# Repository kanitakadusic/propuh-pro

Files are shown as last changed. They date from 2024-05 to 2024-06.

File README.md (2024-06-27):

## Propuh Pro - Sistem za ventilaciju

Projekt u sklopu kursa _Ugradbeni sistemi_ u 2023/24. studijskoj godini.

Cilj ovog projekta je napraviti funkcionalno smart home rješenje koje se sastoji od više distribuiranih komponenti koje međusobno komuniciraju kako bi se uspostavio sistem za ventilaciju.
Sistem se sastoji iz dva dijela - kontrolnog i terenskog podsistema. Terenski dio realizuje ventilaciju dok kontrolni sistem omogućava korisniku uvid u rad i upravljanje ventilacijom.

Sistem primjenu može naći kako u stambenim i ugostiteljskim objektima u vidu ventilacije prostora boravka, tako i u industrijskim okruženjima gdje je potrebno nadzirati temperaturu prostora ili uređaja koji nije neposredno dostupan.

Pored kontrolnog uređaja, sistemom je moguće upravljati i nadzirati ga i putem mobilne aplikacije.

Video prezentacija: https://www.youtube.com/watch?v=3Y28UMO7dcY&t=24s

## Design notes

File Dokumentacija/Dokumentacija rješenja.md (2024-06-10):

# Kontrolni uređaj

## main.py

Zadatak je napraviti koristični interfejs gdje je moguće postaviti željenu temperaturu i brzinu ventilatora za sistem ventilacije.
Izgled interfejsa prošao je više iteracija. Originalna zamisao je bila interakcija sa dva moda ekrana - operacioni i konfiguracijski mod. Međutim, pokazalo se da je bolje imati ekran za konfiguraciju svake od stavki.

Osnovne stavke koje korisnik konfiguriše su:
* *Željena temperatura*
* *Kritična temperatura*
* *Brzina ventilatora*

Pored pogleda na ove tri vrijednosti, postoji i pogled na *mjerenu temperaturu*.

### Display

Za display korišten je LCD sa 16 kolona i 2 reda sa I2C modulom za jednostavniju implementaciju uz pomoć biblioteke [RPI-PICO-I2C-LCD](https://github.com/T-622/RPI-PICO-I2C-LCD). Ova biblioteka dosta pojednostavi rad sa pomenutim LCD ekranom ali se pokazala kao nedovoljno responzivna za češće osvježavanje ekrana. Konfiguracija dimenzija i izlaznih pinova displeja je data ispod. 

```python
from lcd_api import LcdApi
from pico_i2c_lcd import I2cLcd

# Display konfiguracija
I2C_ADDR = 0x27
I2C_NUM_ROWS = 2
I2C_NUM_COLS = 16

I2C_BUS = I2C(1, sda=Pin(26), scl=Pin(27), freq=400000)
LCD_DISPLAY = I2cLcd(I2C_BUS, I2C_ADDR, I2C_NUM_ROWS, I2C_NUM_COLS)
```
Sve interakcije sa ekranom, kao što je postavljanje ili uklanjanje sadržaja izvode se metodama *LCD_DISPLAY* objekta.

### Pogledi

Za rad sa modovima ekrana, uvedena je klasa InterfaceMode koja definiše dozvoljene modove ili poglede na informacije.

Mogući modovi interfejsa su:
* Current temp - zadnja izmjerena temperatura
* Target temp - željena temperatura
* Critical temp - temperatura pri kojoj se pali alarm
* Fan mode - mod ventilatora

Svaki od navedenih modova ima prateći pogled. U prvom redu ekrana ispisan je naziv pogleda dok je u drugom redu ispisana vrijednost.

Za navigaciju između modova i izmjene vrijednosti, koriste se tasteri. Ispis obrađuje funkcija *print_configuration()* koja se poziva nakon svakog klika na taster.

### Tasteri

Tasteri dostupni korisniku su:
* NEXT_MODE_BUTTON - GPIO16
* PREVIOUS_MODE_BUTTON - GPIO19
* INCREASE_BUTTON - GPIO17
* DECREASE_BUTTON - GPIO18

Ovim tasterima korisnik može mijenjati između četri pogleda te povećati i smanjivati vrijednosti u koracima. Nad svakim od tastera definisan je prekid koji poziva funkciju koja obavlja zadatak tog tastera.

```python
# Postavljanje hardverskih prekida
NEXT_MODE_BUTTON.irq(handler=next_mode, trigger=Pin.IRQ_RISING)
INCREASE_BUTTON.irq(handler=increase_value, trigger=Pin.IRQ_RISING)
DECREASE_BUTTON.irq(handler=decrease_value, trigger=Pin.IRQ_RISING)
PREVIOUS_MODE_BUTTON.irq(handler=previous_mode, trigger=Pin.IRQ_RISING)
```

#### Debouncing
Kako se za konfiguraciju vrijednosti koriste fizički tasteri, pogodno je uvesti funkciju za *debouncing*.
```python
debounce = 0

def debouncing():
    global debounce
    if ticks_diff(ticks_ms(), debounce) < DEBOUNCE_TIME_MS:
        return False
    else:
        debounce = ticks_ms()
        return True
```

Konstanta *DEBOUNCE_TIME_MS* određuje period na koji se blokira ponovni unos sa tastera. Vrijednost od 300ms je odabrana nakon više pokušaja upotrebe i dovoljno je kratka da ne dozvoljava bouncing bez značajno utjecaja na korisničko iskustvo.

#### Korak izmjene
Korak izmjene temperature je 0.5°C. Ova vrijednost za korak je odabrana jer predstavlja dobar kompromis između tačnosti senzora temperature i mogućnosti odabranog ventilatora.

Obzirom da vrijednosti koje se dostave sa terenskog uređaja nisu nužno zaokružene na najbližu polovinu stepena, za to se ovdje koristi funkcija:
```python
def round_to_nearest_half(value) -> float:
    return round(value * 2) / 2
```

[LM35](https://www.ti.com/lit/ds/symlink/lm35.pdf) - korišteni senzor, ima grešku reda 0.5°C pri 25°C.

### MQTT Komunikacija

Komunikacija sa terenskim uređajem postiže se putem MQTT brokera. Ovo se pokazalo kao veoma jednostavan pristup rješavanju problema komunikacije više uređaja.

#### WiFi konektivnost

Kako je za MQTT potrebna internet konekcija, potrebno je vršiti spajanje na WiFi mrežu. WiFI SSID i lozinka se konfigurišu u kodu na sljedeći način:
```python
import network

# WiFi konfiguracija
WIFI_SSID = "naziv_mreze"
WIFI_PASSWORD = "password1234"

# Povezivanje na internet
print("Connecting to WiFi: ", WIFI_SSID)
WIFI = network.WLAN(network.STA_IF)
WIFI.active(True)
WIFI.config(pm=0xA11140)
WIFI.connect(WIFI_SSID, WIFI_PASSWORD)

LCD_DISPLAY.putstr("Connecting...")

while not WIFI.isconnected():
    pass

print("Connected to network!")
print("IP address:", WIFI.ifconfig()[0])
```

Obzirom da je sva ostala funkcionalnost uređaja ovisna o internet konekciji, ekran i sve ostale funkcionalnosti su blokirane dok se ne uspostavi WiFi konekcija sa datom mrežom. Na ekranu ostaje ispisan tekst "Connecting..." sve dok se konekcija uspostavlja. Nakon spajanja, u konzoli se ispisuje poruka o uspjehu i lokalna IP adresa.

#### MQTT Broker i teme

MQTT servis postavljen je kako slijedi:
```python
import simple
# MQTT konfiguracija
MQTT_SERVER = "broker.hivemq.com"
MQTT_CLIENT_NAME = "Propuh-Pro-Control"

MQTT_TOPIC_TARGET_TEMP = b"Propuh-Pro/target_temp"
MQTT_TOPIC_CRITICAL_TEMP = b"Propuh-Pro/critical_temp"
MQTT_TOPIC_FAN_MODE = b"Propuh-Pro/fan_mode"
MQTT_TOPIC_MEASURED_TEMP = b"Propuh-Pro/measured_temp"

# Povezivanje na MQTT broker
CLIENT = simple.MQTTClient(client_id=MQTT_CLIENT_NAME, server=MQTT_SERVER, port=1883)
CLIENT.connect()
```

Za svaku od četri stavke, postavljena je tema na MQTT brokeru *broker.himemq.com*.

*target_temp*, *critical_temp* i *measured_temp* predstavljeni su kao realni brojevi dok *fan_mode* uzima jednu od 5 dozvojenih vrijednosti definisanih u FanMode klasi.

Postavljen je klijent MQTT serivsa putem kojeg se šalju i dobavljaju vrijednosti za navedene teme.

#### Slanje podataka

Ovaj uređaj štalje vrijednosti željene i kritične temperature te mod ventilatora.

Nakon bilo koje promjene vrijednosti od strane korisnika, postavlja se timer na 3 sekunde. Nakon 3 sekunde, poziva se funkcija *send_data* koja na broker postavlja navedene vrijednosti.

Ova pauza od 3 sekunde pokazala se kao pogodan pristup za slanje podataka. Obzirom da se ove vrijednosti u praksi ne mijenjaju isuviše često, nije očigledna potreba za periodičnim slanjem.

```python
# Slanje podataka putem MQTT
def send_data(timer):
    publish = str(fan_mode.get_mode())
    CLIENT.publish(MQTT_TOPIC_FAN_MODE, publish)

    publish = str(target_temp)
    CLIENT.publish(MQTT_TOPIC_TARGET_TEMP, publish)

    publish = str(critical_temp)
    CLIENT.publish(MQTT_TOPIC_CRITICAL_TEMP, publish)

    print("Sent!")
```

#### Dobavljanje podataka

Podaci sa MQTT brokera se dobavljaju periodično. Funkcija *recieve_data* se poziva nakon svake sekunde i dobavlja vrijednost mjerene temperature i mod ventilatora koji je potencijalno postavljen na moblinom uređaju.

Kada se ustanovi da je postavljena nova vrijednost na brokeru *check_msg* metodom MQTT klijenta, poziva se *custom_dispatcher* koji tumači dostavljenu poruku na osnovu teme.

```python
# Filtriranje primljenih poruka
def custom_dispatcher(topic, msg):

    if topic == MQTT_TOPIC_MEASURED_TEMP:
        message_arrived_measured_temp(topic, msg)
    elif topic == MQTT_TOPIC_FAN_MODE:
        message_arrived_fan_mode(topic, msg)

CLIENT.set_callback(custom_dispatcher)

# Pretplata na teme
CLIENT.subscribe(MQTT_TOPIC_MEASURED_TEMP)
CLIENT.subscribe(MQTT_TOPIC_FAN_MODE)

# Provjera pristiglih podataka na MQTT
def recieve_data(timer):
    CLIENT.check_msg()
    CLIENT.check_msg()

recieve_DATA_TIMER = Timer(period=1000, mode=Timer.PERIODIC, callback=recieve_data)
```

### Rad sa temperaturama

Za svaku od tema uvedena je varijabla koja će čuvati odgovarajuću vrijednost na uređaju kako bi se njima manipulisalo u ostatku programa.

```python
interface_mode = InterfaceMode()
fan_mode = FanMode()
current_temp = 0.0
target_temp = 21.0
critical_temp = 35.0
```

Navedene početne vrijednosti za *target_temp* i *critical_temp* su odabrane iz razloga što predstavljaju uobičajen opseg temperatura za stambene prostore, mada nema razloga zašto ne mogu biti u bilo kojem drugom opsegu.

Uvedeno je ograničenje oko minimalne razlike kritične i željene temperature. Najmanja razlika je 5.0°C. Ovo je vrijednost za koju možemo pouzdano tvrditi da neće doći do alarma isključivo zbog greške u mjerenju obzirom da korišteni senzor ([LM35](https://www.ti.com/lit/ds/symlink/lm35.pdf)) ima grešku reda 0.5°C pri 25°C. Ova minimalna razlika se može posebno konfigurisati putem izdvojene konstante.

```python
# Dozvoljena razlika željene i kritične temperature
MINIMUM_TEMP_DIFFERENCE = 5.0
```

#### Alarm

Kada mjerena temperatura dosegne kritičnu temperaturu, dolazi do stanja alarma. Kontrolni uređaj na ekranu ispisuje posebnu treptajuću poruku s ciljem da privuće pažnju i upozori na situaciju. Za to vrijeme, neće se ispisivati standardni pogledi. Poruka o alarmu se može skloniti tasterima za promjenu pogleda.

Za potrebe implementacije alarm pogleda, koristi se varibajla *alarm_now*. Varijabla *alarm* služi kao *flag* da se dogodilo prekoračenje temperature što trenutno nema drugih koristi ali otvara mogućnost za neku vrstu dijagnostike u budućnosti.

```python
# Da li se u toku rada programa pojavio alarm
alarm = False
# Da li je trenutno aktivan alarm
alarm_now = False
```

# Terenski uređaj

## main.py

Zadatak je mjeriti i dostavljati temperaturu okruženja, upravljati brzinom ventilatora i signalizirati trenutno stanje. Konfiguracija ovog uređaja se dobavlja sa MQTT brokera.

### Mjerenje temperature

Temperatura se mjeri [LM35](https://www.ti.com/lit/ds/symlink/lm35.pdf) senzorom koji ima grešku reda 0.5°C pri 25°C. Ovaj senzor je odabran zbog jednostavnosti implementacije i korištenja. U opticaju je bio i [DHT11](https://www.mouser.com/datasheet/2/758/dht11-technical-data-sheet-translated-version-1143054.pdf) ali ne nudi dovoljnu preciznost i stabilnost u mjerenjima koja je potrebna za ovakav sistem.

Za konkretan LM35 potrebno je odrediti kalibracijsko offset kako bi mjerenje bilo reprezentativno.

Kako očekujemo da se temperatura prostora neće značajno mijenjati u kratkom periodu vremena, korišteno je periodično uzorkovanje od 10 uzoraka. Na osnovu prosječne vrijednosti uzoraka se određuje temperatura. Kalibracijski offset, broj uzoraka i ulazni pin sa A/D konverzijom se konfigurišu u kodu konstantama navedenim ispod

```python
# LM35 konfiguracija
LM35_CALIBRATION_OFFSET = -1200
LM35_NUMBER_OF_SAMPLES = 10
LM35_SENSOR_PIN = ADC(Pin(28))
```

### Upravljanje ventilatorom

Ventilator se upravlja PWM signalom sa frekvencijom 500Hz. Obzirom da vrijeme za koje se mijenja brzina ventilatora nije od krucijalnog značaja, frekvencija PWM signala ne mora biti izrazito velika.

```python
FAN_PWM = PWM(Pin(22))
FAN_PWM.freq(500)
```

Tačan proračun brzine rada ventilatora provodi objekt klase FanSpeedController koja sadrži svu potrebnu logiku proračuna.

```python
fan_controller = FanSpeedController(22, 30, 22)
```
Detaljnije informacije o klasi FanSpeedController ponuđene su u nastavku (Pomoćne klase / FanSpeedController).

Za početne vrijednosti pri instanciranju odabrane su temperature 22°C za željenu, 30°C za kritičnu i 22°C za trenutnu. Ove vrijedonsti se ponovo postavljaju prvim dobavljanjem podataka sa MQTT servisa.

#### VU Metar

Brzinu i mod ventilatora moguće je vizuleno utvrditi na osnovu šest LED-ova koji svijetle proporcionalno brzini ventilatora

```python
FAN_VU_METER_LEDS = BusOut([4, 5, 6, 7, 8, 9])

# 0 (OFF)       -> 0 upaljenih LED
# 1 (SLOW)      -> 2 upaljene LED
# 2 (NORMAL)    -> 4 upaljene LED
# 3 (FAST)      -> 6 upaljenih LED
```

### Alarm

U slučaju da FanSpeedControler odredi da je trenutna temperatura previsoka, diže se alarm. 
U slučaju alarma, treperi LED i pali se zujalica kako bi se vizuelno i zvukom privukla pažnja korisnika.

Zujanje alarma se može ugasiti tasterom na uređaju, što omogućuje neometano servisiranje koje je eventualno potrebno.

```python
OVERHEATING_LED = Pin(11, Pin.OUT)

ALARM_PWM = PWM(Pin(27))
ALARM_PWM.freq(1000)

ALARM_OFF_BUTTON = Pin(0, Pin.IN)

# Klikom na taster se gasi alarm
ALARM_OFF_BUTTON.irq(handler=turn_alarm_off, trigger=Pin.IRQ_RISING)
```

### MQTT Konektivnost

#### WiFi konektivnost

Identično kao i na kontrolnom uređaju, prvo se uspostavlja WiFi konekcija.

```python
# WiFi konfiguracija 
WIFI_SSID = "naziv_mreze"
WIFI_PASSWORD = "password1234"

# Povezivanje na internet
print("Connecting to WiFi: ", WIFI_SSID)
WIFI = network.WLAN(network.STA_IF)
WIFI.active(True)
WIFI.config(pm=0xA11140) 
WIFI.connect(WIFI_SSID, WIFI_PASSWORD)

while not WIFI.isconnected():
    pass

print("Connected to network!")
print("IP address:", WIFI.ifconfig()[0])
```

#### MQTT Broker i teme

Broker i teme koje se koriste za komunikaciju su identične kao i na kontrolnom uređaju. Jedina razlika je u nazivu klijenta

```python
# MQTT konfiguracija
MQTT_SERVER = "broker.hivemq.com"
MQTT_CLIENT_NAME = "Propuh-Pro-Teren"

MQTT_TOPIC_TARGET_TEMP = b"Propuh-Pro/target_temp"
MQTT_TOPIC_CRITICAL_TEMP = b"Propuh-Pro/critical_temp"
MQTT_TOPIC_FAN_MODE = b"Propuh-Pro/fan_mode"
MQTT_TOPIC_MEASURED_TEMP = b"Propuh-Pro/measured_temp"
```

#### Slanje podataka

Terenski uređaj periodično (svakih 0.5 sekundi) šalje isključivo izmjerenu temperaturu nakon svakog uzorkovanja.

```python
# Povezivanje na MQTT broker
CLIENT = simple.MQTTClient(client_id=MQTT_CLIENT_NAME, server=MQTT_SERVER, port=1883)
CLIENT.connect()

# Uzorkovanje i slanje izmjerene temperature
def check_temperature(t):
    ...
    # Uzorkovanje
    ...
    publish = str(measured_temp)
    CLIENT.publish(MQTT_TOPIC_MEASURED_TEMP, publish)

# Tajmer za očitavanje vrijednosti LM35
CHECK_TEMP_TIMER = Timer(period=500, mode=Timer.PERIODIC, callback=check_temperature)
```

#### Dohvaćanje podataka

Podaci sa MQTT brokera se dobavljaju periodično. Funkcija *recieve_data* se poziva nakon svake sekunde i dobavlja vrijednost željene i kritične temperature i mod ventilatora koji je potencijalno postavljen na moblinom uređaju.

Kada se ustanovi da je postavljena nova vrijednost na brokeru *check_msg* metodom MQTT klijenta, poziva se *custom_dispatcher* koji tumači dostavljenu poruku na osnovu teme.

```python
# Filtriranje primljenih poruka
def custom_dispatcher(topic, msg):
    
    if topic == MQTT_TOPIC_FAN_MODE:
        message_arrived_fan_mode(topic, msg)
    elif topic == MQTT_TOPIC_CRITICAL_TEMP:
        message_arrived_critical_temp(topic, msg)
    elif topic == MQTT_TOPIC_TARGET_TEMP:
        message_arrived_target_temp(topic, msg)

# Pretplata na teme
CLIENT.set_callback(custom_dispatcher)
CLIENT.subscribe(MQTT_TOPIC_FAN_MODE)
CLIENT.subscribe(MQTT_TOPIC_CRITICAL_TEMP)
CLIENT.subscribe(MQTT_TOPIC_TARGET_TEMP)

# Provjera pristiglih podataka na MQTT
def recieve_data(t):
    CLIENT.check_msg()
    CLIENT.check_msg()
    CLIENT.check_msg()

# Tajmer za primanje podataka
RECIEVE_DATA_TIMER = Timer(period=1000, mode=Timer.PERIODIC, callback=recieve_data)
```

# Pomoćne klase

## InterfaceMode

InterfaceMode je pomoćna klasa koja enkapsulira broj i naziv modova ili pogleda na ekran. Ova klasa prati *State pattern* i omogućava promjenu u naredno ili prethodno stanje. Validna stanja su predstavljena kao cijeli brojevi pa se mogu međusobno porediti. Potreba za ovom klasom nastala je jer MicroPython ne poznaje enum klase.

Konstruktor ove klase može da primi jedan parametar - početni pogled, ali je podrazumijevana vrijednost TARGET_TEMP_CONFIG. Primjer instanciranja objekta je dat ispod.

```python
interface_mode = InterfaceMode(InterfaceMode.FAN_CONFIG)
```

Stanja koja ova klasa poznaje su:
```python
VALID_MODES = {
    TARGET_TEMP_CONFIG,
    CRITICAL_TEMP_CONFIG,
    FAN_CONFIG,
    OPERATIONAL,
}
MODE_NAMES = {
    TARGET_TEMP_CONFIG: "TARGET_TEMP_CONFIG",
    CRITICAL_TEMP_CONFIG: "CRITICAL_TEMP_CONFIG",
    FAN_CONFIG: "FAN_CONFIG",
    OPERATIONAL: "OPERATION",
}    
```

Dostupne metode su:
```python
def next(self)          # Naredni mod, ciklično
def previous(self)      # Prethodni mod, ciklično
def get_mode(self)      # Dohvati trenutni mod
def get_mode_name(self) # Dohvati naziv trenutnog moda
```

## FanMode

FanMode je također *State pattern* klasa ali za definisanje modova ventilatora. Tačan intenzitet rada ventilatora nije cilj ove klase. Zapravo, cilj ove klase je da se jasno definišu mogući modovi ventilatora i omogući jasna komunikacija. Kao i za InterfaceMode, stanja se interno čuvaju kao cijeli brojevi.

Konstruktor ove klase može da primi jedan parametar - početni mod, ali je podrazumijevana vrijednost OFF. Primjer instanciranja objekta je dat ispod.

```python
fan_mode = FanMode(FanMode.AUTO)
```

Stanja koja ova klasa poznaje su:
```python
MODE_NAMES = {
    OFF: "OFF",
    SLOW: "SLOW",
    MEDIUM: "MEDIUM",
    FAST: "FAST",
    AUTO: "AUTO",
}

VALID_MODES = {
    OFF,
    SLOW,
    MEDIUM,
    FAST,
    AUTO,
}    
```

Dostupne metode su:
```python
def next(self)          # Naredni mod, ciklično
def previous(self)      # Prethodni mod, ciklično
def get_mode(self)      # Dohvati trenutni mod
def get_mode_name(self) # Dohvati naziv trenutnog moda
```

## FanSpeedController

Za enkapsulaciju logike potrebne za određivanje brzine ventilatora na osnovu relevantnih parametara, kreirana je klasa FanSpeedController.

Parametri potrebni za rad ove klase su:
* target_temp   - double
* critical_temp - double
* current_temp  - double
* fan_mode      - FanMode objekt

Ove vrijednosti se ujedno proslijeđuju konstruktoru u navedenom redoslijedu. Za fan_mode je podrazumijevana vrijednost FanMode(FanMode.OFF).

Dostupne metode su:
```python
def update_current_speed(self)                  
# Proračun brzine na osnovu parametara

def set_fan_mode(self, new_fan_mode)            
# Postavljanje jednog od modova za ventilator

def get_fan_mode(self)                          
# Dobavljanje trenutnog moda za ventilator

def set_current_temp(self, new_current_temp)    
# Postavljanje trenutne temperature

def set_target_temp(self, new_target_temp)      
# Postavljanje željene temperature

def set_critical_temp(self, new_critical_temp)  
# Postavljanje kritične temperature

def is_alarm(self)                              
# Provjeri je li alarmantna temperatura

def get_speed_percent(self)                     
# Dohvati brzinu u procentima

def get_speed_u16(self)                         
# Dohvati temperaturu u opsegu [0, 65535]

def get_led_binary(self)                        
# Dohvati stanje LED-ova

def turn_alarm_off(self)                        
# Ugasi alarm
```

Opsezi brzine su:
```python
# 0 (OFF)       -> 0%
# 1 (SLOW)      -> 50%
# 2 (NORMAL)    -> 75%
# 3 (FAST)      -> 100%
```

Za automatski mod, proračun se vrši po opsezima proračunatog procenta kao:

```python
# < -0.1        -> OFF
# [-0.1, 0.05)  -> OFF/SLOW
# [0.05, 0.2)   -> SLOW
# [0.2, 0.3)    -> SLOW/NORMAL
# [0.3, 0.5)    -> NORMAL
# [0.5, 0.6)    -> NORMAL/FAST
# >= 0.6        -> FAST
```

## BusOut

Za potrebe rada sa nizom LED-ova, uvedena je klasa BusOut.

BusOut omogućujue upravljanjem sa više digitalnih izlaza istovremeno tako što se proslijedi cijeli broj koji predstavlja željeno stanje izlaza.

Primjer instanciranja i postavljanja vrijednosti:
```python
bus_out = BusOut(Pin(16), Pin(17), Pin(18))

bus_out.setValue(0b101)
# Pin 16 i 18 su uključeni dok je Pin 17 isključen
```

Dostupne metode su:
```python
def set_value(self, val)
# Postavlja zadatu vrijednost val (integer ili binarni broj)

def size(self)
# Dohvaća broj pinova okjima se upravlja

def get_value(self)
# Dohvaća trenutno postavljenu vrijednost

def shift_right(self, shift_amount=1)
# Pomjera vrijednost izlaza udesno za dati broj bita

def shift_left(self, shift_amount=1)
# Pomjera vrijednost izlaza ulijevo za dati broj bita
```

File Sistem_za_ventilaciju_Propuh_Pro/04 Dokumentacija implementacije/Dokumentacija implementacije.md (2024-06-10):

<!-- TOC -->
# Propuh Pro - Tehnička dokumentacija
Za potrebe detaljnog tehničkog razumijevanja, ovdje su ponuđeni implementacijski detalji i motivacije za rješenja važnih problema u procesu razvoja ovog sistema.

U nastavku su ponuđeni detalji tehničkim licima potrebni za održavanje i nadogradnju postojećih mogućnosti sistema.

<!-- TOC start (generated with https://github.com/derlin/bitdowntoc) -->

- [Kontrolni uređaj](#kontrolni-ureaj)
   * [main.py](#mainpy)
      + [Display](#display)
      + [Pogledi](#pogledi)
      + [Tasteri](#tasteri)
         - [Debouncing](#debouncing)
         - [Korak izmjene](#korak-izmjene)
      + [MQTT Komunikacija](#mqtt-komunikacija)
         - [WiFi konektivnost](#wifi-konektivnost)
         - [MQTT Broker i teme](#mqtt-broker-i-teme)
         - [Slanje podataka](#slanje-podataka)
         - [Dobavljanje podataka](#dobavljanje-podataka)
      + [Rad sa temperaturama](#rad-sa-temperaturama)
         - [Alarm](#alarm)
- [Terenski uređaj](#terenski-ureaj)
   * [main.py](#mainpy-1)
      + [Mjerenje temperature](#mjerenje-temperature)
      + [Upravljanje ventilatorom](#upravljanje-ventilatorom)
         - [VU Metar](#vu-metar)
      + [Alarm](#alarm-1)
      + [MQTT Konektivnost](#mqtt-konektivnost)
         - [WiFi konektivnost](#wifi-konektivnost-1)
         - [MQTT Broker i teme](#mqtt-broker-i-teme-1)
         - [Slanje podataka](#slanje-podataka-1)
         - [Dohvaćanje podataka](#dohvaanje-podataka)
- [Pomoćne klase](#pomone-klase)
   * [InterfaceMode](#interfacemode)
   * [FanMode](#fanmode)
   * [FanSpeedController](#fanspeedcontroller)
   * [BusOut](#busout)

<!-- TOC end -->

<!-- TOC -->
# Kontrolni uređaj
<!-- TOC -->
## main.py
Zadatak je napraviti koristični interfejs gdje je moguće postaviti željenu temperaturu i brzinu ventilatora za sistem ventilacije.
Izgled interfejsa prošao je više iteracija. Originalna zamisao je bila interakcija sa dva moda ekrana - operacioni i konfiguracijski mod. Međutim, pokazalo se da je bolje imati ekran za konfiguraciju svake od stavki.
Osnovne stavke koje korisnik konfiguriše su:
* *Željena temperatura*
* *Kritična temperatura*
* *Brzina ventilatora*
Pored pogleda na ove tri vrijednosti, postoji i pogled na *mjerenu temperaturu*.

<!-- TOC -->
### Display
Za display korišten je LCD sa 16 kolona i 2 reda sa I2C modulom za jednostavniju implementaciju uz pomoć biblioteke [RPI-PICO-I2C-LCD](https://github.com/T-622/RPI-PICO-I2C-LCD). Ova biblioteka dosta pojednostavi rad sa pomenutim LCD ekranom ali se pokazala kao nedovoljno responzivna za češće osvježavanje ekrana. Konfiguracija dimenzija i izlaznih pinova displeja je data ispod. 
```python
from lcd_api import LcdApi
from pico_i2c_lcd import I2cLcd

# Display konfiguracija
I2C_ADDR = 0x27
I2C_NUM_ROWS = 2
I2C_NUM_COLS = 16

I2C_BUS = I2C(1, sda=Pin(26), scl=Pin(27), freq=400000)
LCD_DISPLAY = I2cLcd(I2C_BUS, I2C_ADDR, I2C_NUM_ROWS, I2C_NUM_COLS)
```
Sve interakcije sa ekranom, kao što je postavljanje ili uklanjanje sadržaja izvode se metodama *LCD_DISPLAY* objekta.

<!-- TOC -->
### Pogledi
Za rad sa modovima ekrana, uvedena je klasa InterfaceMode koja definiše dozvoljene modove ili poglede na informacije.
Mogući modovi interfejsa su:
* Current temp - zadnja izmjerena temperatura
* Target temp - željena temperatura
* Critical temp - temperatura pri kojoj se pali alarm
* Fan mode - mod ventilatora

Svaki od navedenih modova ima prateći pogled. U prvom redu ekrana ispisan je naziv pogleda dok je u drugom redu ispisana vrijednost.

Za navigaciju između modova i izmjene vrijednosti, koriste se tasteri. Ispis obrađuje funkcija *print_configuration()* koja se poziva nakon svakog klika na taster.

<!-- TOC -->
### Tasteri
Tasteri dostupni korisniku su:
* NEXT_MODE_BUTTON - GPIO16
* PREVIOUS_MODE_BUTTON - GPIO19
* INCREASE_BUTTON - GPIO17
* DECREASE_BUTTON - GPIO18

Ovim tasterima korisnik može mijenjati između četri pogleda te povećati i smanjivati vrijednosti u koracima. Nad svakim od tastera definisan je prekid koji poziva funkciju koja obavlja zadatak tog tastera.
```python
# Postavljanje hardverskih prekida
NEXT_MODE_BUTTON.irq(handler=next_mode, trigger=Pin.IRQ_RISING)
INCREASE_BUTTON.irq(handler=increase_value, trigger=Pin.IRQ_RISING)
DECREASE_BUTTON.irq(handler=decrease_value, trigger=Pin.IRQ_RISING)
PREVIOUS_MODE_BUTTON.irq(handler=previous_mode, trigger=Pin.IRQ_RISING)
```
<!-- TOC -->
#### Debouncing
Kako se za konfiguraciju vrijednosti koriste fizički tasteri, pogodno je uvesti funkciju za *debouncing*.
```python
debounce = 0
def debouncing():
    global debounce
    if ticks_diff(ticks_ms(), debounce) < DEBOUNCE_TIME_MS:
        return False
    else:
        debounce = ticks_ms()
        return True
```
Konstanta *DEBOUNCE_TIME_MS* određuje period na koji se blokira ponovni unos sa tastera. Vrijednost od 300ms je odabrana nakon više pokušaja upotrebe i dovoljno je kratka da ne dozvoljava bouncing bez značajno utjecaja na korisničko iskustvo.

<!-- TOC -->
#### Korak izmjene
Korak izmjene temperature je 0.5°C. Ova vrijednost za korak je odabrana jer predstavlja dobar kompromis između tačnosti senzora temperature i mogućnosti odabranog ventilatora.
Obzirom da vrijednosti koje se dostave sa terenskog uređaja nisu nužno zaokružene na najbližu polovinu stepena, za to se ovdje koristi funkcija:
```python
def round_to_nearest_half(value) -> float:
    return round(value * 2) / 2
```
[LM35](https://www.ti.com/lit/ds/symlink/lm35.pdf) - korišteni senzor, ima grešku reda 0.5°C pri 25°C.

<!-- TOC -->
### MQTT Komunikacija
Komunikacija sa terenskim uređajem postiže se putem MQTT brokera. Ovo se pokazalo kao veoma jednostavan pristup rješavanju problema komunikacije više uređaja.

<!-- TOC -->
#### WiFi konektivnost
Kako je za MQTT potrebna internet konekcija, potrebno je vršiti spajanje na WiFi mrežu. WiFI SSID i lozinka se konfigurišu u kodu na sljedeći način:
```python
import network

# WiFi konfiguracija
WIFI_SSID = "naziv_mreze"
WIFI_PASSWORD = "password1234"

# Povezivanje na internet
print("Connecting to WiFi: ", WIFI_SSID)
WIFI = network.WLAN(network.STA_IF)
WIFI.active(True)
WIFI.config(pm=0xA11140)
WIFI.connect(WIFI_SSID, WIFI_PASSWORD)

LCD_DISPLAY.putstr("Connecting...")

while not WIFI.isconnected():
    pass

print("Connected to network!")
print("IP address:", WIFI.ifconfig()[0])
```
Obzirom da je sva ostala funkcionalnost uređaja ovisna o internet konekciji, ekran i sve ostale funkcionalnosti su blokirane dok se ne uspostavi WiFi konekcija sa datom mrežom. Na ekranu ostaje ispisan tekst "Connecting..." sve dok se konekcija uspostavlja. Nakon spajanja, u konzoli se ispisuje poruka o uspjehu i lokalna IP adresa.

<!-- TOC -->
#### MQTT Broker i teme
MQTT servis postavljen je kako slijedi:
```python
import simple
# MQTT konfiguracija
MQTT_SERVER = "broker.hivemq.com"
MQTT_CLIENT_NAME = "Propuh-Pro-Control"

MQTT_TOPIC_TARGET_TEMP = b"Propuh-Pro/target_temp"
MQTT_TOPIC_CRITICAL_TEMP = b"Propuh-Pro/critical_temp"
MQTT_TOPIC_FAN_MODE = b"Propuh-Pro/fan_mode"
MQTT_TOPIC_MEASURED_TEMP = b"Propuh-Pro/measured_temp"

# Povezivanje na MQTT broker
CLIENT = simple.MQTTClient(client_id=MQTT_CLIENT_NAME, server=MQTT_SERVER, port=1883)
CLIENT.connect()
```
Za svaku od četri stavke, postavljena je tema na MQTT brokeru *broker.himemq.com*.

*target_temp*, *critical_temp* i *measured_temp* predstavljeni su kao realni brojevi dok *fan_mode* uzima jednu od 5 dozvojenih vrijednosti definisanih u FanMode klasi.

Postavljen je klijent MQTT serivsa putem kojeg se šalju i dobavljaju vrijednosti za navedene teme.

<!-- TOC -->
#### Slanje podataka
Ovaj uređaj štalje vrijednosti željene i kritične temperature te mod ventilatora.
Nakon bilo koje promjene vrijednosti od strane korisnika, postavlja se timer na 3 sekunde. Nakon 3 sekunde, poziva se funkcija *send_data* koja na broker postavlja navedene vrijednosti.

Ova pauza od 3 sekunde pokazala se kao pogodan pristup za slanje podataka. Obzirom da se ove vrijednosti u praksi ne mijenjaju isuviše često, nije očigledna potreba za periodičnim slanjem.

```python
# Slanje podataka putem MQTT
def send_data(timer):
    publish = str(fan_mode.get_mode())
    CLIENT.publish(MQTT_TOPIC_FAN_MODE, publish)

    publish = str(target_temp)
    CLIENT.publish(MQTT_TOPIC_TARGET_TEMP, publish)

    publish = str(critical_temp)
    CLIENT.publish(MQTT_TOPIC_CRITICAL_TEMP, publish)

    print("Sent!")
```

<!-- TOC -->
#### Dobavljanje podataka
Podaci sa MQTT brokera se dobavljaju periodično. Funkcija *recieve_data* se poziva nakon svake sekunde i dobavlja vrijednost mjerene temperature i mod ventilatora koji je potencijalno postavljen na moblinom uređaju.
Kada se ustanovi da je postavljena nova vrijednost na brokeru *check_msg* metodom MQTT klijenta, poziva se *custom_dispatcher* koji tumači dostavljenu poruku na osnovu teme.
```python
# Filtriranje primljenih poruka
def custom_dispatcher(topic, msg):

    if topic == MQTT_TOPIC_MEASURED_TEMP:
        message_arrived_measured_temp(topic, msg)
    elif topic == MQTT_TOPIC_FAN_MODE:
        message_arrived_fan_mode(topic, msg)

CLIENT.set_callback(custom_dispatcher)

# Pretplata na teme
CLIENT.subscribe(MQTT_TOPIC_MEASURED_TEMP)
CLIENT.subscribe(MQTT_TOPIC_FAN_MODE)

# Provjera pristiglih podataka na MQTT
def recieve_data(timer):
    CLIENT.check_msg()
    CLIENT.check_msg()

recieve_DATA_TIMER = Timer(period=1000, mode=Timer.PERIODIC, callback=recieve_data)
```

<!-- TOC -->
### Rad sa temperaturama
Za svaku od tema uvedena je varijabla koja će čuvati odgovarajuću vrijednost na uređaju kako bi se njima manipulisalo u ostatku programa.
```python
interface_mode = InterfaceMode()
fan_mode = FanMode()
current_temp = 0.0
target_temp = 21.0
critical_temp = 35.0
```
Navedene početne vrijednosti za *target_temp* i *critical_temp* su odabrane iz razloga što predstavljaju uobičajen opseg temperatura za stambene prostore, mada nema razloga zašto ne mogu biti u bilo kojem drugom opsegu.

Uvedeno je ograničenje oko minimalne razlike kritične i željene temperature. Najmanja razlika je 5.0°C. Ovo je vrijednost za koju možemo pouzdano tvrditi da neće doći do alarma isključivo zbog greške u mjerenju obzirom da korišteni senzor ([LM35](https://www.ti.com/lit/ds/symlink/lm35.pdf)) ima grešku reda 0.5°C pri 25°C. Ova minimalna razlika se može posebno konfigurisati putem izdvojene konstante.
```python
# Dozvoljena razlika željene i kritične temperature
MINIMUM_TEMP_DIFFERENCE = 5.0
```

<!-- TOC -->
#### Alarm
Kada mjerena temperatura dosegne kritičnu temperaturu, dolazi do stanja alarma. Kontrolni uređaj na ekranu ispisuje posebnu treptajuću poruku s ciljem da privuće pažnju i upozori na situaciju. Za to vrijeme, neće se ispisivati standardni pogledi. Poruka o alarmu se može skloniti tasterima za promjenu pogleda.
Za potrebe implementacije alarm pogleda, koristi se varibajla *alarm_now*. Varijabla *alarm* služi kao *flag* da se dogodilo prekoračenje temperature što trenutno nema drugih koristi ali otvara mogućnost za neku vrstu dijagnostike u budućnosti.
```python
# Da li se u toku rada programa pojavio alarm
alarm = False
# Da li je trenutno aktivan alarm
alarm_now = False
```

<!-- TOC -->
# Terenski uređaj
<!-- TOC -->
## main.py
Zadatak je mjeriti i dostavljati temperaturu okruženja, upravljati brzinom ventilatora i signalizirati trenutno stanje. Konfiguracija ovog uređaja se dobavlja sa MQTT brokera.

<!-- TOC -->
### Mjerenje temperature
Temperatura se mjeri [LM35](https://www.ti.com/lit/ds/symlink/lm35.pdf) senzorom koji ima grešku reda 0.5°C pri 25°C. Ovaj senzor je odabran zbog jednostavnosti implementacije i korištenja. U opticaju je bio i [DHT11](https://www.mouser.com/datasheet/2/758/dht11-technical-data-sheet-translated-version-1143054.pdf) ali ne nudi dovoljnu preciznost i stabilnost u mjerenjima koja je potrebna za ovakav sistem.

Za konkretan LM35 potrebno je odrediti kalibracijsko offset kako bi mjerenje bilo reprezentativno.

Kako očekujemo da se temperatura prostora neće značajno mijenjati u kratkom periodu vremena, korišteno je periodično uzorkovanje od 10 uzoraka. Na osnovu prosječne vrijednosti uzoraka se određuje temperatura. Kalibracijski offset, broj uzoraka i ulazni pin sa A/D konverzijom se konfigurišu u kodu konstantama navedenim ispod
```python
# LM35 konfiguracija
LM35_CALIBRATION_OFFSET = -1200
LM35_NUMBER_OF_SAMPLES = 10
LM35_SENSOR_PIN = ADC(Pin(28))
```

<!-- TOC -->
### Upravljanje ventilatorom
Ventilator se upravlja PWM signalom sa frekvencijom 500Hz. Obzirom da vrijeme za koje se mijenja brzina ventilatora nije od krucijalnog značaja, frekvencija PWM signala ne mora biti izrazito velika.
```python
FAN_PWM = PWM(Pin(22))
FAN_PWM.freq(500)
```

Tačan proračun brzine rada ventilatora provodi objekt klase FanSpeedController koja sadrži svu potrebnu logiku proračuna.
```python
fan_controller = FanSpeedController(22, 30, 22)
```
Detaljnije informacije o klasi FanSpeedController ponuđene su u nastavku (Pomoćne klase / FanSpeedController).

Za početne vrijednosti pri instanciranju odabrane su temperature 22°C za željenu, 30°C za kritičnu i 22°C za trenutnu. Ove vrijedonsti se ponovo postavljaju prvim dobavljanjem podataka sa MQTT servisa.

<!-- TOC -->
#### VU Metar
Brzinu i mod ventilatora moguće je vizuleno utvrditi na osnovu šest LED-ova koji svijetle proporcionalno brzini ventilatora
```python
FAN_VU_METER_LEDS = BusOut([4, 5, 6, 7, 8, 9])

# 0 (OFF)       -> 0 upaljenih LED
# 1 (SLOW)      -> 2 upaljene LED
# 2 (NORMAL)    -> 4 upaljene LED
# 3 (FAST)      -> 6 upaljenih LED
```

<!-- TOC -->
### Alarm
U slučaju da FanSpeedControler odredi da je trenutna temperatura previsoka, diže se alarm. 
U slučaju alarma, treperi LED i pali se zujalica kako bi se vizuelno i zvukom privukla pažnja korisnika.

Zujanje alarma se može ugasiti tasterom na uređaju, što omogućuje neometano servisiranje koje je eventualno potrebno.
```python
OVERHEATING_LED = Pin(11, Pin.OUT)

ALARM_PWM = PWM(Pin(27))
ALARM_PWM.freq(1000)

ALARM_OFF_BUTTON = Pin(0, Pin.IN)

# Klikom na taster se gasi alarm
ALARM_OFF_BUTTON.irq(handler=turn_alarm_off, trigger=Pin.IRQ_RISING)
```

<!-- TOC -->
### MQTT Konektivnost
<!-- TOC -->
#### WiFi konektivnost
Identično kao i na kontrolnom uređaju, prvo se uspostavlja WiFi konekcija.
```python
# WiFi konfiguracija 
WIFI_SSID = "naziv_mreze"
WIFI_PASSWORD = "password1234"

# Povezivanje na internet
print("Connecting to WiFi: ", WIFI_SSID)
WIFI = network.WLAN(network.STA_IF)
WIFI.active(True)
WIFI.config(pm=0xA11140) 
WIFI.connect(WIFI_SSID, WIFI_PASSWORD)

while not WIFI.isconnected():
    pass

print("Connected to network!")
print("IP address:", WIFI.ifconfig()[0])
```

<!-- TOC -->
#### MQTT Broker i teme
Broker i teme koje se koriste za komunikaciju su identične kao i na kontrolnom uređaju. Jedina razlika je u nazivu klijenta
```python
# MQTT konfiguracija
MQTT_SERVER = "broker.hivemq.com"
MQTT_CLIENT_NAME = "Propuh-Pro-Teren"

MQTT_TOPIC_TARGET_TEMP = b"Propuh-Pro/target_temp"
MQTT_TOPIC_CRITICAL_TEMP = b"Propuh-Pro/critical_temp"
MQTT_TOPIC_FAN_MODE = b"Propuh-Pro/fan_mode"
MQTT_TOPIC_MEASURED_TEMP = b"Propuh-Pro/measured_temp"
```

<!-- TOC -->
#### Slanje podataka
Terenski uređaj periodično (svakih 0.5 sekundi) šalje isključivo izmjerenu temperaturu nakon svakog uzorkovanja.

```python
# Povezivanje na MQTT broker
CLIENT = simple.MQTTClient(client_id=MQTT_CLIENT_NAME, server=MQTT_SERVER, port=1883)
CLIENT.connect()

# Uzorkovanje i slanje izmjerene temperature
def check_temperature(t):
    ...
    # Uzorkovanje
    ...
    publish = str(measured_temp)
    CLIENT.publish(MQTT_TOPIC_MEASURED_TEMP, publish)

# Tajmer za očitavanje vrijednosti LM35
CHECK_TEMP_TIMER = Timer(period=500, mode=Timer.PERIODIC, callback=check_temperature)
```

<!-- TOC -->
#### Dohvaćanje podataka
Podaci sa MQTT brokera se dobavljaju periodično. Funkcija *recieve_data* se poziva nakon svake sekunde i dobavlja vrijednost željene i kritične temperature i mod ventilatora koji je potencijalno postavljen na moblinom uređaju.

Kada se ustanovi da je postavljena nova vrijednost na brokeru *check_msg* metodom MQTT klijenta, poziva se *custom_dispatcher* koji tumači dostavljenu poruku na osnovu teme.
```python
# Filtriranje primljenih poruka
def custom_dispatcher(topic, msg):
    
    if topic == MQTT_TOPIC_FAN_MODE:
        message_arrived_fan_mode(topic, msg)
    elif topic == MQTT_TOPIC_CRITICAL_TEMP:
        message_arrived_critical_temp(topic, msg)
    elif topic == MQTT_TOPIC_TARGET_TEMP:
        message_arrived_target_temp(topic, msg)

# Pretplata na teme
CLIENT.set_callback(custom_dispatcher)
CLIENT.subscribe(MQTT_TOPIC_FAN_MODE)
CLIENT.subscribe(MQTT_TOPIC_CRITICAL_TEMP)
CLIENT.subscribe(MQTT_TOPIC_TARGET_TEMP)

# Provjera pristiglih podataka na MQTT
def recieve_data(t):
    CLIENT.check_msg()
    CLIENT.check_msg()
    CLIENT.check_msg()

# Tajmer za primanje podataka
RECIEVE_DATA_TIMER = Timer(period=1000, mode=Timer.PERIODIC, callback=recieve_data)
```

<!-- TOC -->
# Pomoćne klase
<!-- TOC -->
## InterfaceMode
InterfaceMode je pomoćna klasa koja enkapsulira broj i naziv modova ili pogleda na ekran. Ova klasa prati *State pattern* i omogućava promjenu u naredno ili prethodno stanje. Validna stanja su predstavljena kao cijeli brojevi pa se mogu međusobno porediti. Potreba za ovom klasom nastala je jer MicroPython ne poznaje enum klase.

Konstruktor ove klase može da primi jedan parametar - početni pogled, ali je podrazumijevana vrijednost TARGET_TEMP_CONFIG. Primjer instanciranja objekta je dat ispod.
```python
interface_mode = InterfaceMode(InterfaceMode.FAN_CONFIG)
```

Stanja koja ova klasa poznaje su:
```python
VALID_MODES = {
    TARGET_TEMP_CONFIG,
    CRITICAL_TEMP_CONFIG,
    FAN_CONFIG,
    OPERATIONAL,
}
MODE_NAMES = {
    TARGET_TEMP_CONFIG: "TARGET_TEMP_CONFIG",
    CRITICAL_TEMP_CONFIG: "CRITICAL_TEMP_CONFIG",
    FAN_CONFIG: "FAN_CONFIG",
    OPERATIONAL: "OPERATION",
}    
```
Dostupne metode su:
```python
def next(self)          # Naredni mod, ciklično
def previous(self)      # Prethodni mod, ciklično
def get_mode(self)      # Dohvati trenutni mod
def get_mode_name(self) # Dohvati naziv trenutnog moda
```

<!-- TOC -->
## FanMode
FanMode je također *State pattern* klasa ali za definisanje modova ventilatora. Tačan intenzitet rada ventilatora nije cilj ove klase. Zapravo, cilj ove klase je da se jasno definišu mogući modovi ventilatora i omogući jasna komunikacija. Kao i za InterfaceMode, stanja se interno čuvaju kao cijeli brojevi.

Konstruktor ove klase može da primi jedan parametar - početni mod, ali je podrazumijevana vrijednost OFF. Primjer instanciranja objekta je dat ispod.
```python
fan_mode = FanMode(FanMode.AUTO)
```

Stanja koja ova klasa poznaje su:
```python
MODE_NAMES = {
    OFF: "OFF",
    SLOW: "SLOW",
    MEDIUM: "MEDIUM",
    FAST: "FAST",
    AUTO: "AUTO",
}

VALID_MODES = {
    OFF,
    SLOW,
    MEDIUM,
    FAST,
    AUTO,
}    
```

Dostupne metode su:
```python
def next(self)          # Naredni mod, ciklično
def previous(self)      # Prethodni mod, ciklično
def get_mode(self)      # Dohvati trenutni mod
def get_mode_name(self) # Dohvati naziv trenutnog moda
```

<!-- TOC -->
## FanSpeedController
Za enkapsulaciju logike potrebne za određivanje brzine ventilatora na osnovu relevantnih parametara, kreirana je klasa FanSpeedController.

Parametri potrebni za rad ove klase su:
* target_temp   - double
* critical_temp - double
* current_temp  - double
* fan_mode      - FanMode objekt

Ove vrijednosti se ujedno proslijeđuju konstruktoru u navedenom redoslijedu. Za fan_mode je podrazumijevana vrijednost FanMode(FanMode.OFF).

Dostupne metode su:
```python
def update_current_speed(self)                  
# Proračun brzine na osnovu parametara

def set_fan_mode(self, new_fan_mode)            
# Postavljanje jednog od modova za ventilator

def get_fan_mode(self)                          
# Dobavljanje trenutnog moda za ventilator

def set_current_temp(self, new_current_temp)    
# Postavljanje trenutne temperature

def set_target_temp(self, new_target_temp)      
# Postavljanje željene temperature

def set_critical_temp(self, new_critical_temp)  
# Postavljanje kritične temperature

def is_alarm(self)                              
# Provjeri je li alarmantna temperatura

def get_speed_percent(self)                     
# Dohvati brzinu u procentima

def get_speed_u16(self)                         
# Dohvati temperaturu u opsegu [0, 65535]

def get_led_binary(self)                        
# Dohvati stanje LED-ova

def turn_alarm_off(self)                        
# Ugasi alarm
```

Opsezi brzine su:
```python
# 0 (OFF)       -> 0%
# 1 (SLOW)      -> 50%
# 2 (NORMAL)    -> 75%
# 3 (FAST)      -> 100%
```

Za automatski mod, proračun se vrši po opsezima proračunatog procenta kao:
```python
# < -0.1        -> OFF
# [-0.1, 0.05)  -> OFF/SLOW
# [0.05, 0.2)   -> SLOW
# [0.2, 0.3)    -> SLOW/NORMAL
# [0.3, 0.5)    -> NORMAL
# [0.5, 0.6)    -> NORMAL/FAST
# >= 0.6        -> FAST
```

<!-- TOC -->
## BusOut
Za potrebe rada sa nizom LED-ova, uvedena je klasa BusOut.
BusOut omogućujue upravljanjem sa više digitalnih izlaza istovremeno tako što se proslijedi cijeli broj koji predstavlja željeno stanje izlaza.
Primjer instanciranja i postavljanja vrijednosti:
```python
bus_out = BusOut(Pin(16), Pin(17), Pin(18))
bus_out.setValue(0b101)
# Pin 16 i 18 su uključeni dok je Pin 17 isključen
```

Dostupne metode su:
```python
def set_value(self, val)
# Postavlja zadatu vrijednost val (integer ili binarni broj)

def size(self)
# Dohvaća broj pinova okjima se upravlja

def get_value(self)
# Dohvaća trenutno postavljenu vrijednost

def shift_right(self, shift_amount=1)
# Pomjera vrijednost izlaza udesno za dati broj bita

def shift_left(self, shift_amount=1)
# Pomjera vrijednost izlaza ulijevo za dati broj bita
```

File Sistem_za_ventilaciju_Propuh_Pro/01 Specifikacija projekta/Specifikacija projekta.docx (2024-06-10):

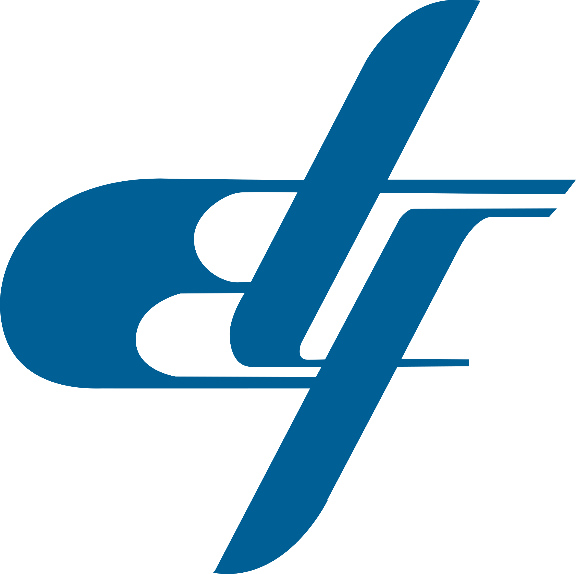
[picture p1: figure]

UNIVERZITET U SARAJEVU

ELEKTROTEHNIČKI FAKULTET

ODSJEK ZA RAČUNARSTVO I INFORMATIKU

UGRADBENI SISTEMI

Sistem za ventilaciju – Propuh Pro

PROJEKTNI ZADATAK

Studenti:

Merjem Gutošić

Kanita Kadušić

Mirza Mahmutović

Haris Mališević

Nastavni ansambl:

Red. prof. dr. Samim Konjicija, dipl. ing. el.

Selmir Gajip, mr. el. - dipl. ing. el.

Sarajevo, juni 2024.

# Sadržaj

# 1 Specifikacija projekta

Cilj ovog projekta je napraviti funkcionalno smart home rješenje, koje se sastoji od više distribuiranih komponenti koje međusobno komuniciraju. Imajući u vidu dostupne resurse i realnu primjenu u praksi, tema projekta je uspostavljanje sistema za ventilaciju.

Sistem se sastoji iz dva dijela – kontrolnog i terenskog podsistema. Terenski dio realizira ventilaciju dok kontrolni dio sistema omogućava korisniku uvid u rad terenskog podsistema i upravljanje njime.

Sistem primjenu može naći kako u stambenim i ugostiteljskim objektima u vidu ventilacije prostora boravka, tako i u industrijskim okruženjima gdje je potrebno nadzirati temperaturu prostora ili uređaja koji nije neposredno dostupan.

Pored kontrolnog uređaja, sistemom je moguće upravljati i nadzirati ga i putem mobilne aplikacije.

## 1.1 Funkcionalnosti sistema

### 1.1.1 Postavljanje željene i kritične temperature i režima rada ventilatora

U sklopu kontrolnog dijela sistema, korisnik ima mogućnost podešavanja željene i kritične temperature koristeći dva tastera (jedan za povećavanje, drugi za smanjivanje temperature). Također, korisnik može odabrati i željeni način rada ventilatora. O čemu se radi? Naime, ventilator ima četiri moguća režima:

- slabi – ventilator puše malom snagom
- srednji – ventilator puše srednjom snagom
- jaki – ventilator puše velikom snagom
- automatski – sistem, na osnovu odnosa trenutne, željene i kritične temperature, određuje optimalnu snagu ventilatora, u cilju postizanja željene temperature

Definisana željena temperatura figurira samo ukoliko se ventilator nalazi u automatskom režimu rada. Slabi, srednji i jaki režim rada podrazumijevaju da ventilator rashlađuje odgovarajućom snagom sve dok korisnik ne bude zahtijevao drugačije.

### 1.1.2 Praćenje visine temperature, režima i jačine puhanja ventilatora

Kontrolni podsistem daje uvid u kompletan rad sistema. Putem displeja se prikazuje trenutna temperatura, koja dolazi od strane terenskog podsistema, te režim rada ventilatora i jačina puhanja istog (displej, prikazom odgovarajućih znakova, realizira varijantu VU metra).

Jačina puhanja ventilatora u sklopu terenskog dijela sistema se prikazuje realizirajući VU metar uz pomoć LED dioda.

### 1.1.3 Mijenjanje prikaza displeja

Kontrolni podsistem daje mogućnost da se, pritiskom na odgovarajuće tastere, mijenja prikaz displeja. Dva prikaza podrazumijevaju podešavanje željene i kritične temperature (naravno, sistem vodi računa o validnosti unosa). Sljedeći prikaz omogućava kako podešavanje režima rada ventilatora, tako i praćenje njegove jačine puhanja (s obzirom da automatski režim sam pronalazi optimalanu jačinu puhanja). Četvrti, ujedno i posljednji prikaz, podrazumijeva ispis trenutne temperature koju dobija od strane terenskog podsistema.

### 1.1.4 Upozorenje pri dostizanju kritične temperature

Kako je već rečeno, korisnik definiše željenu i kritičnu temperaturu. Ukoliko terenski podsistem izmjeri temperaturu koja prelazi granicu definisanu kritičnom temperaturom, korisnik biva obaviješten slanjem upozorenja.

Upozorenje se realizira na dva načina. Prvi podrazumijeva prikaz upozorenja putem displeja u sklopu kontrolog podsistema, dok drugi podrazumijeva zvučno oglašavanje u sklopu terenskog podsistema. Osim alarma, koji se može ugasiti pritiskom na taster, odgovarajuća LED dioda blinka dok se situacija ne normalizuje i sistem ne resetuje.

### 1.1.5 Mijenjanje režima rada ventilatora putem mobilnog uređaja

Koristeći IoT MQTT Panel aplikaciju, korisnik ima mogućnost mijenjati režim rada ventilatora, neovisno od lokacije na kojoj se nalazi.

## 1.2 Hardverski resursi

### 1.2.1 PicoETF – kontrolni podsistem

| Komponenta | Opis | Količina
1 | taster | digitalni ulaz | 4
2 | LCD displej | izlazna komponenta | 1

### 1.2.2 Pico – terenski podsistem

| Komponenta | Opis | Količina
1 | LM35 temperaturni senzor | analogni ulaz | 1
2 | DC motor | PWM izlaz | 1
3 | LED dioda | digitalni izlaz | 7
4 | piezo (zvučnik/buzzer) | PWM izlaz | 1

### 1.2.3 Dodatna oprema

Od dodatne opreme, koristit će se i ventilator, mobilni uređaj, baterija 9V , otpornici, konektori, tranzistor, sigurnosna dioda i breadboard-i.

# 2 Zaključak

Što se tiče mogućih proširenja projekta, njih je moguće razmatrati u dva smjera. Sistem za ventilaciju je moguće nadograditi dodavanjem pomoćnih ventilatora. Na primjer, u automatskom režimu rada, pomoćni ventilator bi se uključivao kada sistem procijeni da nije u mogućnosti postići željenu temperaturu s jednim ventilatorom ili ukoliko sistem zaključi da bi rashlađivanje pomoću jednog ventilatora bilo isuviše sporo. S druge strane, u sistem bi se mogli dodati novi senzori, kao što su senzor dima i vlažnosti, čime bi se uvele nove funkcionalnosti kojima korisnik raspolaže.

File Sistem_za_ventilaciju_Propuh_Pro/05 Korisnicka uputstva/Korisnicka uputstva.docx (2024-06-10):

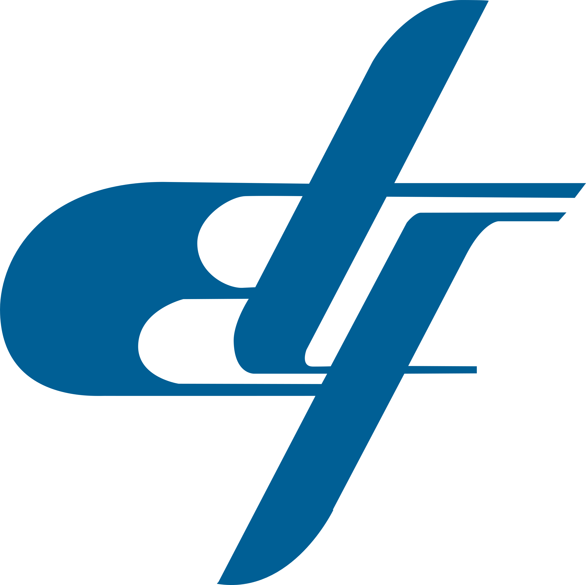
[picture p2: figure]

UNIVERZITET U SARAJEVU

ELEKTROTEHNIČKI FAKULTET

ODSJEK ZA RAČUNARSTVO I INFORMATIKU

UGRADBENI SISTEMI

Sistem za ventilaciju – Propuh Pro

Korisnička uputstva

Sarajevo, juni 2024.

# Poštovani korisnici

Ispred vas se nalazi uputstvo za upotrebu Propuh-Pro sistema za ventilaciju. Propuh-Pro predstavlja jednostavan smart home sistem čiji je glavni cilj regulisanje temperature prema željama korisnika korištenjem ventilatora. Nudi mogućnost podešavanja željene temperature i jačinu rada ventilatora od strane korisnika, podešavanje kritične temperature kao indikatora o performansama sistema, uvid u trenutnu temperaturu i podatke koji su uneseni, te vizuelnu i audio signalizaciju vezanu za rad sistema.

Sistem je jednostavan za korištenje i u potpunosti prilagođen korisniku. Sastoji se od kontrolnog i terenskog uređaja koji su međusobno povezani na programskom nivou. Dijelovi nisu povezani fizički pa sistem radi bez obzira na njihovu međusobnu udaljenost. Po želji, sistem je moguće nadzirati i podešavati i putem mobilne aplikacije, čime on postaje univerzalniji.

Propuh-Pro sistem za ventilaciju može se koristiti u bilo kojem prostoru i kontekstu vezanom za ventilaciju i regulaciju temperature, te njegov puni potencijal zavisi samo od mašte korisnika.

Molimo Vas da pročitate uputstva do kraja kako biste izbjegli bilo kakve nejasnoće.

# Sadržaj

# 1 Karakteristike

- Rashlađivanje

Osnovna svrha i mogućnost sistema je raslađivanje prostora na željenu temperaturu. Prostor i kontekst u kojem će se koristiti korisnik može prilagođavati po želji i u skladu sa veličinom ventilatora.

- Mjerenje trenutne temperature

Sistem ima ugrađen temperaturni senzor pomoću kojeg u toku rada mjeri trenutnu temperaturu u prostoru. Izmjerenu temperaturu je moguće vidjeti na ekranu kontrolnog sistema.

- Podešavanje temperature

Iako sistem sadrži unaprijed definisanu vrijednost željene temperature, poželjno je da se ista podesi u skladu sa namjenom sistema. Sistem će nastojati, prema konfiguracijama korisnika, da održi odabranu temperaturu.

- Podešavanje kritične temperature

Kritična temperatura je jedan od parametara sistema koji određuje njegovu funkcionalnost. Razlika između kritične i željene temperature ne smije biti manja od 5°C, u suprotnom sistem ne dopušta dalje smanjivanje kritične, odnosno povećavanje željene temperature

- Podešavanje jačine ventilatora

Pored temperature, potrebno je podesiti i jačinu rada ventilatora. Moguće je birati jedan od 4 moda:

1. OFF – sistem ne radi
2. SLOW – slabi intenzitet
3. MEDIUM – srednje jaki intenzitet
4. FAST – jaki intenzitet
5. AUTO – automatski režim rada (detaljnije objašnjen u nastavku)

Nakon podešavanja jačine rada ventilatora, ventilator započinje rad s jačinom u skladu s odabranom opcijom.

- Uvid u podatke

Na kontrolnom uređaju sistem pruža mogućnost pregleda unesenih parametara (jačine rada, željene i kritične temperature), kao i prikaz trenutne temperature u prostoru putem poruke na display-u.

Na terenskom uređaju jačina rada ventilatora vizuelno je prikazana u vidu VU metra putem LED dioda.

- AUTO mod rada ventilatora

Sistem ima mogućnost korištenja AUTO moda. U ovom modu, sistem samostalno podešava jačinu rada ventilatora, u zavisnosti od vrijednosti trenutne temperature.

- Kontrola sistema pomoću mobilne aplikacije

Po želji, jačina rada ventilatora može se kontrolisati i putem mobilne aplikacije. Željenu i kritičnu temperaturu, potrebno je regulisati putem kontrolnog uređaja.

- Fizička nezavisnost uređaja

Kontrolni i terenski uređaj nisu fizički spojeni i ne ovise od međusobne udaljenosti, pa sistem može da radi i kada se uređaji nalaze u različitim prostorijama.

- Signalizacija u slučaju dostizanja kritične temperature u prostoru

Ukoliko trenutna temperature dostigne vrijednost jednaku ili veću od kritične temperature, na terenskom uređaju pali se zvučni alarm i svjetlosna signalizacija putem posljednje LED diode na sistemu. Na kontrolnom uređaju prikazuje se odgovarajuća poruka.

Svrha signalizacija u ovom slučaju je ukazivanje korisniku od strane sistema da trenutni rad sistema nije u potpunosti prilagođen smanjivanju trenutne temperature.

# 2 Komponente

## 2.1 Kontrolni uređaj

Kontrolni uređaj služi za podešavanje parametara na osnovu kojih radi ventilator. Parametri koji se podešavaju su:

- željena temperatura
- jačina rada ventilatora
- kritična temperature

Na kontrolnom uređaju nalazi se display koji prikazuje unesene podatke i parametre sistema, te 4 dugmeta pomoću kojih se parametri unose i mijenja trenutni prikaz:

- prethodni korisnički mod
- smanji (temperaturu) / prethodni mod ventilatora
- povećaj (temperaturu) / sljedeći mod ventilatora
- sljedeći korisnički mod

## 2.2 Terenski uređaj

Terenski uređaj je uređaj koji realizuje samu ventilaciju te se u skladu s tim na njemu nalazi više komponenti:

- ventilator koji se pokreće i radi na osnovu podataka unesenih putem kontrolnog uređaja
- alarm koji je zadužen za zvučnu signalizaciju u slučaju da trenutna temperatura dostigne kritičnu temperaturu
- svjetlosne diode koje pružaju vizuelni prikaz trenutnog rada, tj. jačine rada ventilatora u vidu VU metra
- dugme za gašenje alarma
- temperaturni senzor

# 3 Upute za korištenje

## 3.1 Pokretanje sistema

Sistem neće raditi ukoliko neki od uređaja nije povezan na određenu WiFi mrežu, pa je prije samog korištenja i paljenja sistema neophodno obezbijediti stabilnu WiFi konekciju.

Oba uređaja sistema je potrebno povezati sa dotokom struje (kabl spojiti u utičnicu) što će pokrenuti paljenje sistema. Nakon paljenja, sistem će pristupiti procesu povezivanja sa WiFi mrežom, te će se na ekranu na kontrolnom uređaju prikazati poruka: "Connecting..."

Nakon povezivanja na ekranu će se prikazati podaci o željenoj temperaturi, što znači da je sistem povezan i spreman za rad.

## 3.2 Korisnički modovi

Parametri koji se unose, kao i informacije koje se prikazuju na ekranu ne prikazuju se i ne biraju se odjednom, nego u zavisnosti od odabranog korisničkog moda. Moguće je odabrati jedan od 4 moda:

- Željena temperatura – podešava se i prikazuje željena temperature u vidu poruke:

"Target temp: " + unesena temperatura

- Kritična temperatura – podešava se i prikazuje kritična temperature u vidu poruke:

"Critical temp: " + unesena temperatura

- Konfiguracija ventilatora – podešava se i prikazuje jačina rada ventilatora u vidu poruke:

"Fan speed: " + prikaz putem simbola + unesena jačina

- Trenutna temperatura – prikazuje se trenutna temperatura u prostoru u vidu poruke:

"Current temp: " + izmjerena temperatura

BITNO: Odgovarajući podaci se mogu podesiti i vidjeti samo ukoliko se sistem nalazi u odgovarajućem modu.

## 3.3 Prolazak kroz modove

Promjena modova realizuje se klikom na jedno od dva krajnja dugmeta:

  - krajnje lijevo dugme – jedan mod unazad
  - krajnje desno dugme – jedan mod naprijed

Prilikom klika na dugme prikaz na ekranu će se promijeniti i prikazati odgovarajuću poruku. Modovi se mijenjaju i ciklično tako da se kontinuiranim klikanjem na krajnje lijevo, odnosno krajnje desno dugme, sistem može vratiti u isti mod.

## 3.4 Podešavanje temperature

I željena i kritična temperatura se podešavaju na isti način na kontrolnom uređaju.

Prije podešavanja željene i kritične temperature bit će ponuđene početne vrijednosti:

- željena temperature: 21°C
- kritična temperature: 35°C

Da bi ventilator radio, nije neophodno mijenjati početne vrijednosti navedenih temperature. Međutim, preporučuje se prilagođavanje ovih temperatura samoj namjeni sistema.

Podešavanje temperature se vrši klikom na neko od dva dugmeta u sredini na kontrolnom uređaju na sljedeći način:

- smanjivanje temperature – drugo dugme po redu s lijeva za svaki klik željenu/kritičnu temperaturu smanjuje za 0.5°C
- povećavanje temperature – treće dugme po redu s lijeva za svaki klik željenu/kritičnu temperaturu povećava za 0.5°C

## 3.5 Podešavanje jačine rada ventilatora

Jačina ventilatora se slično kao i korisnički modovi može podesiti klikom na neko od dva dugmeta u sredini na kontrolnom uređaju na sljedeći način:

- jedan mod nazad – drugo dugme po redu s lijeva za svaki klik vraća mod ventilatora za jedan niže, tj. za svaki klik ventilator će puhati manjom jačinom
- jedan mod naprijed – treće dugme po redu s lijeva za svaki klik postavlja mod ventilatora za jedan više, tj. za svaki klik ventilator će puhati većom jačinom
- ukoliko se ventilator nalazi u FAST modu klikom za prelaz u sljedeći mod će se preći u AUTO mod
- kroz modove se kreće cirkularno prema prethodno navedenom rasporedu (nakon AUTO moda prelazi se u OFF ukoliko se prelazi naprijed i iz OFF moda se prelazi u AUTO mod ukoliko se prelazi naprijed)

*Modovi tj.moguće jačine rada ventilatora i njihov raspored navedeni su u karakteristikama sistema.

## 3.6 Pokretanje ventilatora

Rad ventilatora zavisi direktno od njegovog moda. Ukoliko je mod odabran ventilator će početi puhati u skladu s njim.

## 3.7 Gašenje ventilatora

Rad ventilatora zavisi direktno od njegovog moda što znači da ukoliko je odabran mod OFF ventilator će prestati puhati, tj. ugasit će se.

## 3.8 Podešavanje kritične temperature

Razlika između kritične i željene temperature ne smije biti manja od 5°C, u suprotnom sistem ne dozvoljava dalju promjenu temperature na sljedeći način:

- Prilikom povećavanja željene temperature, nakon što ona dostigne navedenu razliku od od 5°C u odnosu na kritičnu temperaturu neće se više moći povećavati bez prethodnog korigovanja kritične temperature
- Prilikom smanjivanja kritične temperature, nakon što ona dostigne navedenu razliku od 5°C u odnosu na trenutnu temperaturu neće se više moći smanjivati bez prethodnog korigovanja trenutne temperature

## 3.9 Dostizanje željene temperature

Nakon što se trenutna temperatura prostora spusti na željenu temperaturu sistem nastavlja da radi u prethodno odabranom modu, sve dok se ne desi promjena podataka od strane korisnika.

## 3.10 Paljenje alarma

Paljenje alarma se dešava kada trenutna temperatura dostigne vrijednost kritične temperature. U suštini alarm se oglašava onda kada rad sistema prema trenutnim postavkama parametara nije optimalan u odnosu na trenutno izmjerenu temperaturu u prostoru. Pored zvučnog alarma, upalit će se i svjetlosna diode koja će se naizmjenično paliti i gasiti.

Alarm je potrebno ugasiti klikom na taster koji se nalazi na terenskom uređaju.

BITNO: Nakon gašenja alarma, sistem je potrebno isključiti (prekinuti dotok struje) i ponovo pokrenuti kako bi se alarm po potrebi opet upalio.

## 3.11 Lokacija senzora i očitavanja temperature

BITNO: Treba imati u vidu da se temperaturni senzor nalazi na terenskom uređaju, što znači da će temperatura koja se prikazuje kao trenutna biti izmjerena u prostoru gdje se nalazi terenski uređaj. U skladu s tim, željena temperatura koju prostor treba dostići korištenjem sistema treba biti u prostoru u kojem se nalazi terenski uređaj.

# 4 Rad s mobilnom aplikacijom

Nakon što se pristupi mobilnoj aplikaciji bit će ponuđen sljedeći prikaz ekrana:

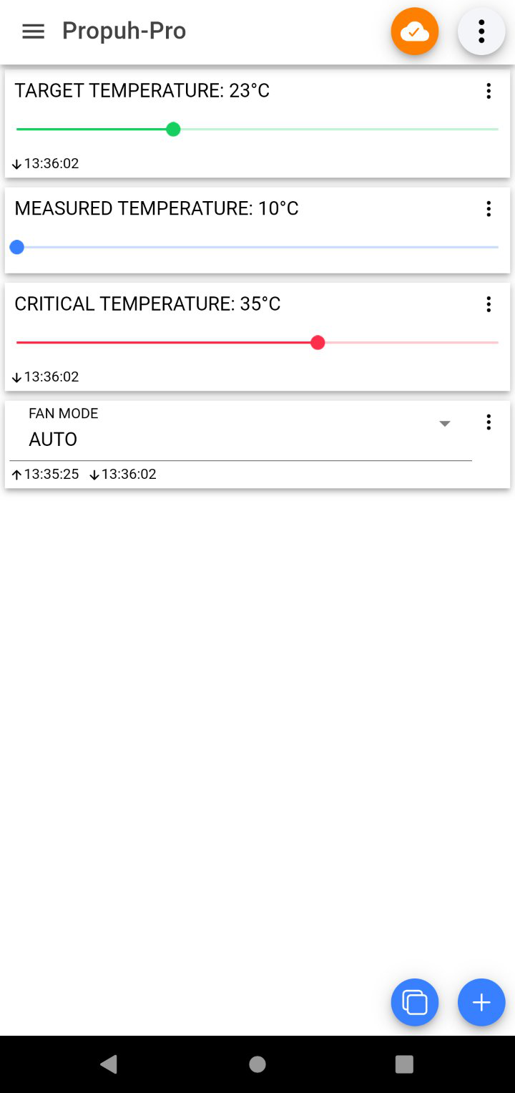
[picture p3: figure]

Mogućnosti koje se nude prilikom korištenja mobilne aplikacije su:

- uvid u željenu temperaturu – labela pod nazivom „Target temperature“
- uvid u trenutnu temperaturu – labela pod nazivom „Measured temperature“
- uvid u kritičnu temperaturu – labela pod nazivom „Critical temperature“
- uvid u odabrani mod rada ventilatora – labela pod nazivom „FAN MODE“ uz mogućnost promjene odabranog moda

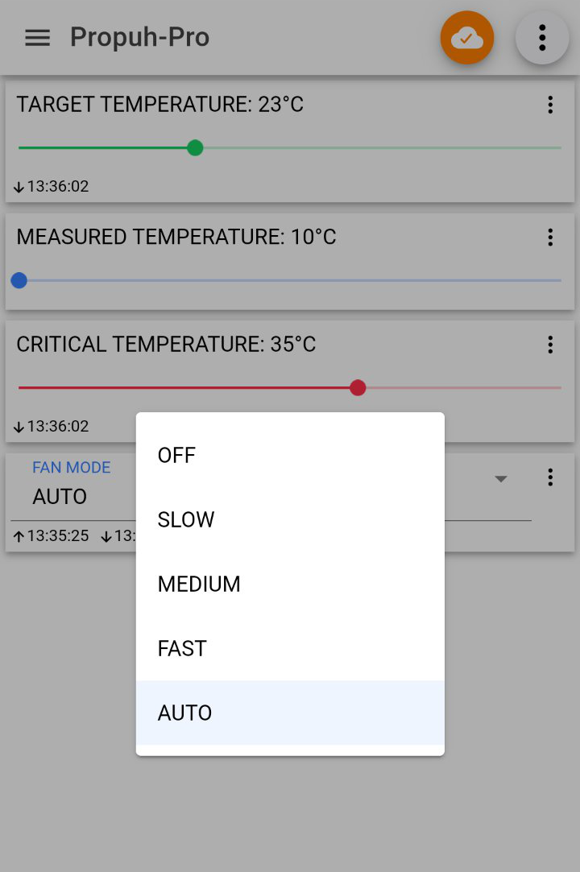
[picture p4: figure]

## 4.1 Izmjena rada moda ventilatora

Nakon klika na labelu sa nazivom “FAN MODE” prikazat će se pravougaonik sa mogućim opcijama, nakon čega je potrebno klikom odabrati novi željeni mod

# 5 Održavanje

- Da bi sistem radio mora biti omogućen dotok struje
- Da bi sistem bio funkcionalan mora biti omogućena stabilna WiFi konekcija
- Sistem ne smije biti u dodiru sa vodom

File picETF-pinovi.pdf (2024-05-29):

Raspored pinova razvojnog sistema picoETF

LED diode

LED0 | GP4
LED1 | GP5
LED2 | GP6
LED3 | GP7
LED4 | GP8
LED5 | GP9
LED6 | GP10
LED7 | GP11
G | GP12
B | GP13
R | GP14

Tasteri

T1 | GP0
T2 | GP1
T3 | GP2
T4 | GP3

Matrična tastatura

ROW1 | GP21
ROW2 | GP22
ROW3 | GP26
ROW4 | GP27
COL1 | GP0
COL2 | GP1
COL3 | GP2
COL4 | GP3

7-segmentni displej

D1 | GP4
D2 | GP5
D3 | GP6
D4 | GP7
A | GP8
B | GP9
C | GP10
D | GP11
E | GP12
F | GP13
G | GP14
DP | GP15

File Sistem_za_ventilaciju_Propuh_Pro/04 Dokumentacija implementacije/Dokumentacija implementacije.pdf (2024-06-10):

# Propuh Pro - Tehnička dokumentacija

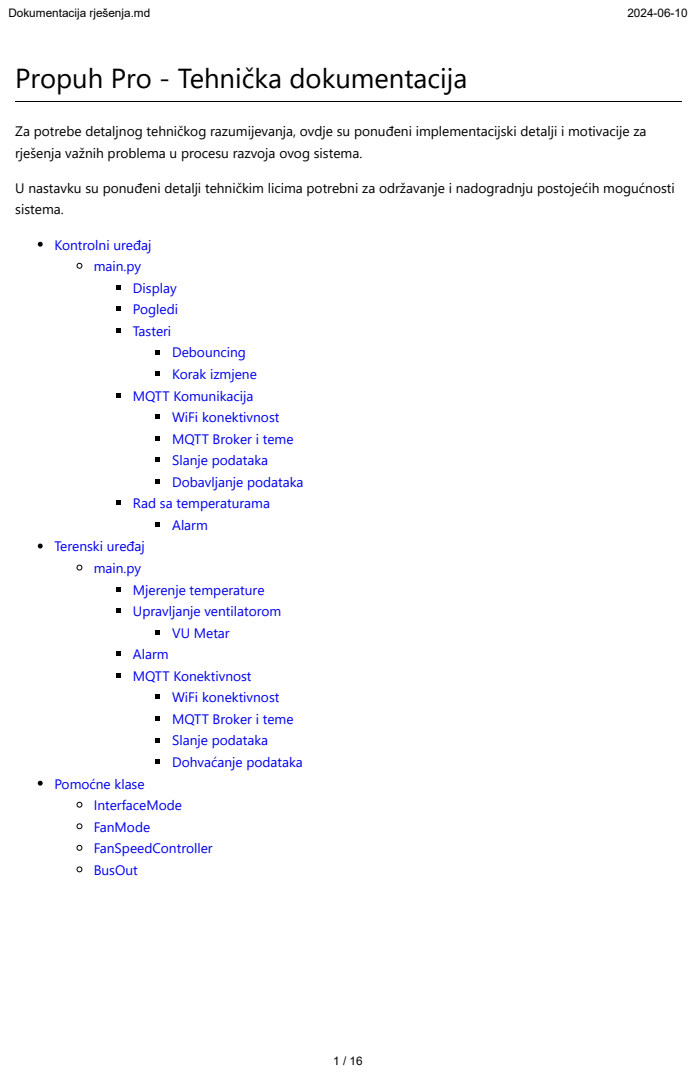
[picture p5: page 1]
Dokumentacija rješenja.md; Pomoćne klase InterfaceMode FanMode FanSpeedController BusOut

Za potrebe detaljnog tehničkog razumijevanja, ovdje su ponuđeni implementacijski detalji i motivacije za
rješenja važnih problema u procesu razvoja ovog sistema.

U nastavku su ponuđeni detalji tehničkim licima potrebni za održavanje i nadogradnju postojećih mogućnosti
sistema.

Kontrolni uređaj
main.py
Display
Pogledi
Tasteri
Debouncing
Korak izmjene
MQTT Komunikacija
WiFi konektivnost
MQTT Broker i teme
Slanje podataka
Dobavljanje podataka
Rad sa temperaturama
Alarm

Terenski uređaj
Mjerenje temperature
Upravljanje ventilatorom
VU Metar
MQTT Konektivnost
Dohvaćanje podataka

# Kontrolni uređaj

## main.py

Zadatak je napraviti koristični interfejs gdje je moguće postaviti željenu temperaturu i brzinu ventilatora za sistem ventilacije. Izgled interfejsa prošao je više iteracija. Originalna zamisao je bila interakcija sa dva moda ekrana - operacioni i konfiguracijski mod. Međutim, pokazalo se da je bolje imati ekran za konfiguraciju svake od stavki. Osnovne stavke koje korisnik konfiguriše su:

Željena temperatura
Kritična temperatura
Brzina ventilatora Pored pogleda na ove tri vrijednosti, postoji i pogled na mjerenu temperaturu.
Display

Za display korišten je LCD sa 16 kolona i 2 reda sa I2C modulom za jednostavniju implementaciju uz pomoć biblioteke RPI-PICO-I2C-LCD. (https://github.com/T-622/RPI-PICO-I2C-LCD) Ova biblioteka dosta pojednostavi rad sa pomenutim LCD ekranom ali se pokazala kao nedovoljno responzivna za češće osvježavanje ekrana. Konfiguracija dimenzija i izlaznih pinova displeja je data ispod.

from lcd_api import LcdApi
from pico_i2c_lcd import I2cLcd

# Display konfiguracija

I2C_ADDR = 0x27
I2C_NUM_ROWS = 2
I2C_NUM_COLS = 16

I2C_BUS = I2C(1, sda=Pin(26), scl=Pin(27), freq=400000)
LCD_DISPLAY = I2cLcd(I2C_BUS, I2C_ADDR, I2C_NUM_ROWS, I2C_NUM_COLS)

Sve interakcije sa ekranom, kao što je postavljanje ili uklanjanje sadržaja izvode se metodama LCD_DISPLAY objekta.

Pogledi

Za rad sa modovima ekrana, uvedena je klasa InterfaceMode koja definiše dozvoljene modove ili poglede na informacije. Mogući modovi interfejsa su:

Current temp - zadnja izmjerena temperatura
Target temp - željena temperatura
Critical temp - temperatura pri kojoj se pali alarm
Fan mode - mod ventilatora

Svaki od navedenih modova ima prateći pogled. U prvom redu ekrana ispisan je naziv pogleda dok je u drugom redu ispisana vrijednost.

Za navigaciju između modova i izmjene vrijednosti, koriste se tasteri. Ispis obrađuje funkcija print_configuration() koja se poziva nakon svakog klika na taster.
Tasteri

Tasteri dostupni korisniku su:

NEXT_MODE_BUTTON - GPIO16
PREVIOUS_MODE_BUTTON - GPIO19
INCREASE_BUTTON - GPIO17
DECREASE_BUTTON - GPIO18

Ovim tasterima korisnik može mijenjati između četri pogleda te povećati i smanjivati vrijednosti u koracima. Nad svakim od tastera definisan je prekid koji poziva funkciju koja obavlja zadatak tog tastera.

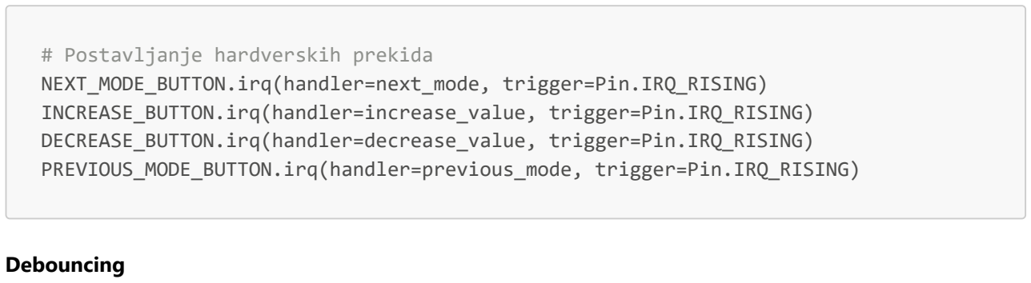
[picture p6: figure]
# Postavljanje hardverskih prekida NEXT_MODE_BUTTON.irq(handler=next_mode, trigger=Pin.IRQ_RISING) INCREASE_BUTTON.irq(handler=increase_value, trigger=Pin.IRQ_RISING) DECREASE_BUTTON.irq(handler=decrease_value, trigger=Pin.IRQ_RISING) PREVIOUS_MODE_BUTTON.irq(handler=previous_mode, trigger=Pin.IRQ_RISING); Debouncing

Kako se za konfiguraciju vrijednosti koriste fizički tasteri, pogodno je uvesti funkciju za debouncing.

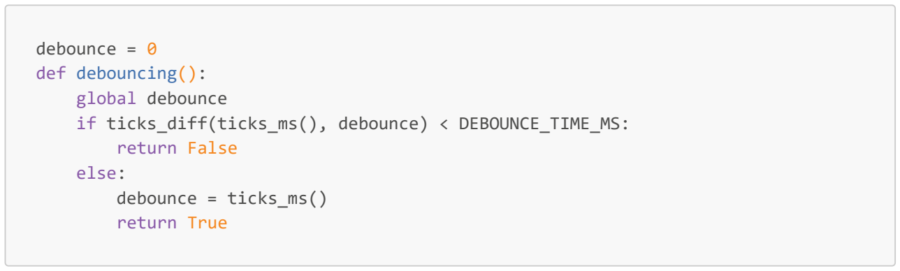
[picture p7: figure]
debounce = 0 def debouncing(): global debounce if ticks_diff(ticks_ms(), debounce) < DEBOUNCE_TIME_MS: return False else: debounce = ticks_ms() return True

Konstanta DEBOUNCE_TIME_MS određuje period na koji se blokira ponovni unos sa tastera. Vrijednost od 300ms je odabrana nakon više pokušaja upotrebe i dovoljno je kratka da ne dozvoljava bouncing bez značajno utjecaja na korisničko iskustvo.

Korak izmjene

Korak izmjene temperature je 0.5°C. Ova vrijednost za korak je odabrana jer predstavlja dobar kompromis između tačnosti senzora temperature i mogućnosti odabranog ventilatora. Obzirom da vrijednosti koje se dostave sa terenskog uređaja nisu nužno zaokružene na najbližu polovinu stepena, za to se ovdje koristi

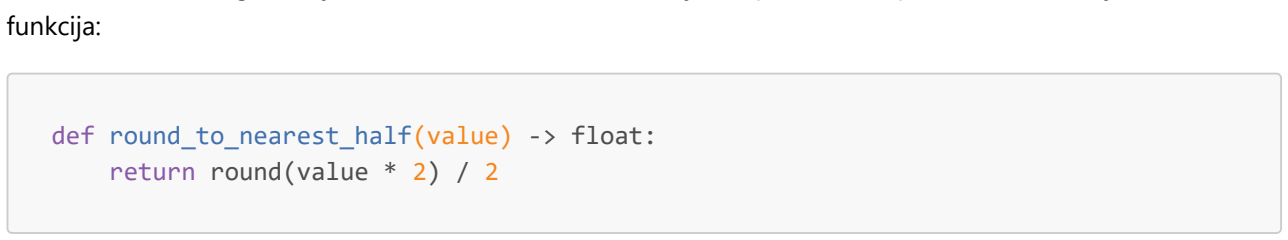
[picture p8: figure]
funkcija:; def round_to_nearest_half(value) -> float: return round(value * 2) / 2

LM35 (https://www.ti.com/lit/ds/symlink/lm35.pdf) - korišteni senzor, ima grešku reda 0.5°C pri 25°C.
MQTT Komunikacija

Komunikacija sa terenskim uređajem postiže se putem MQTT brokera. Ovo se pokazalo kao veoma jednostavan pristup rješavanju problema komunikacije više uređaja.

WiFi konektivnost

Kako je za MQTT potrebna internet konekcija, potrebno je vršiti spajanje na WiFi mrežu. WiFI SSID i lozinka se konfigurišu u kodu na sljedeći način:

import network

# WiFi konfiguracija

WIFI_SSID = "naziv_mreze"
WIFI_PASSWORD = "password1234"

# Povezivanje na internet

print("Connecting to WiFi: ", WIFI_SSID) WIFI = network.WLAN(network.STA_IF) WIFI.active(True)
WIFI.config(pm=0xA11140)
WIFI.connect(WIFI_SSID, WIFI_PASSWORD)

LCD_DISPLAY.putstr("Connecting...")

while not WIFI.isconnected():
pass

print("Connected to network!") print("IP address:", WIFI.ifconfig()[0])

Obzirom da je sva ostala funkcionalnost uređaja ovisna o internet konekciji, ekran i sve ostale funkcionalnosti su blokirane dok se ne uspostavi WiFi konekcija sa datom mrežom. Na ekranu ostaje ispisan tekst "Connecting..." sve dok se konekcija uspostavlja. Nakon spajanja, u konzoli se ispisuje poruka o uspjehu i lokalna IP adresa.

MQTT Broker i teme

MQTT servis postavljen je kako slijedi:

import simple
# MQTT konfiguracija

MQTT_SERVER = "broker.hivemq.com"
MQTT_CLIENT_NAME = "Propuh-Pro-Control"

MQTT_TOPIC_TARGET_TEMP = b"Propuh-Pro/target_temp" MQTT_TOPIC_CRITICAL_TEMP = b"Propuh-Pro/critical_temp" MQTT_TOPIC_FAN_MODE = b"Propuh-Pro/fan_mode"
MQTT_TOPIC_MEASURED_TEMP = b"Propuh-Pro/measured_temp"

# Povezivanje na MQTT broker

CLIENT = simple.MQTTClient(client_id=MQTT_CLIENT_NAME, server=MQTT_SERVER, port=1883)
CLIENT.connect()

Za svaku od četri stavke, postavljena je tema na MQTT brokeru broker.himemq.com.

target_temp, critical_temp i measured_temp predstavljeni su kao realni brojevi dok fan_mode uzima jednu od 5 dozvojenih vrijednosti definisanih u FanMode klasi.

Postavljen je klijent MQTT serivsa putem kojeg se šalju i dobavljaju vrijednosti za navedene teme.

Slanje podataka

Ovaj uređaj štalje vrijednosti željene i kritične temperature te mod ventilatora. Nakon bilo koje promjene vrijednosti od strane korisnika, postavlja se timer na 3 sekunde. Nakon 3 sekunde, poziva se funkcija send_data koja na broker postavlja navedene vrijednosti.

Ova pauza od 3 sekunde pokazala se kao pogodan pristup za slanje podataka. Obzirom da se ove vrijednosti u praksi ne mijenjaju isuviše često, nije očigledna potreba za periodičnim slanjem.

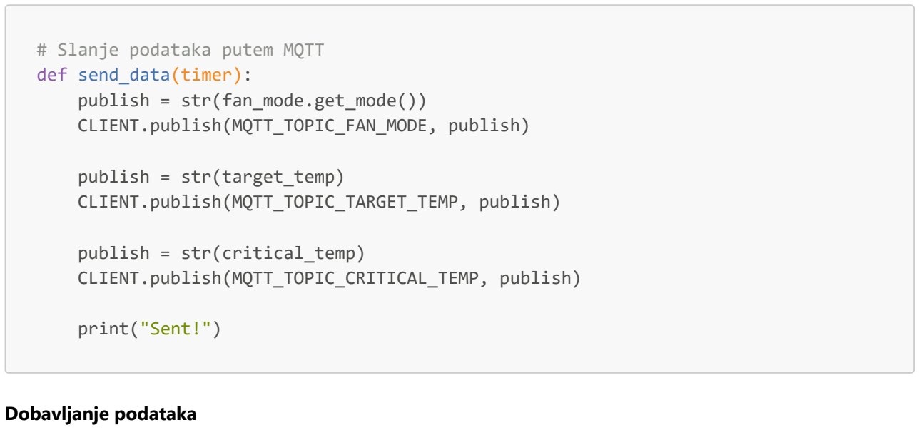
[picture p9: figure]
# Slanje podataka putem MQTT def send_data(timer): publish = str(fan_mode.get_mode()) CLIENT.publish(MQTT_TOPIC_FAN_MODE, publish); publish = str(target_temp) CLIENT.publish(MQTT_TOPIC_TARGET_TEMP, publish); publish = str(critical_temp) CLIENT.publish(MQTT_TOPIC_CRITICAL_TEMP, publish); print("Sent!"); Dobavljanje podataka

Podaci sa MQTT brokera se dobavljaju periodično. Funkcija recieve_data se poziva nakon svake sekunde i dobavlja vrijednost mjerene temperature i mod ventilatora koji je potencijalno postavljen na moblinom uređaju. Kada se ustanovi da je postavljena nova vrijednost na brokeru check_msg metodom MQTT klijenta, poziva se custom_dispatcher koji tumači dostavljenu poruku na osnovu teme.

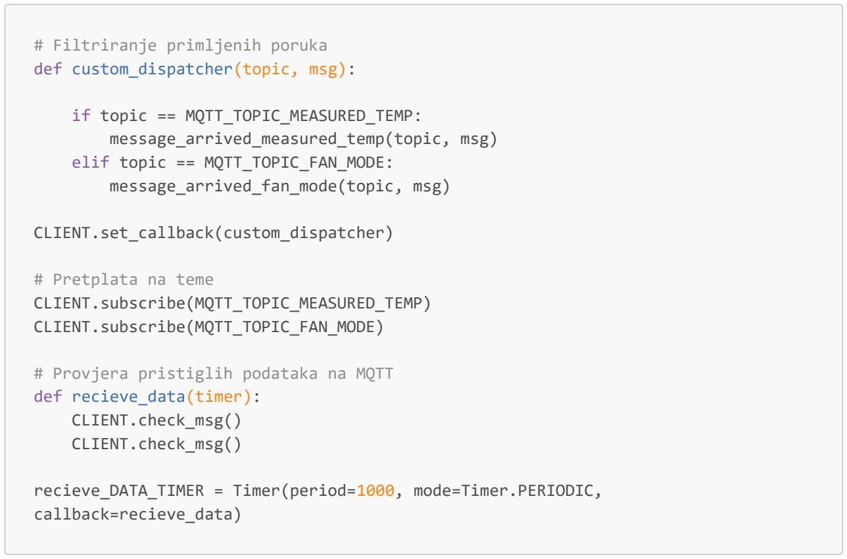
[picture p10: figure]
# Filtriranje primljenih poruka def custom_dispatcher(topic, msg):; if topic == MQTT_TOPIC_MEASURED_TEMP: message_arrived_measured_temp(topic, msg) elif topic == MQTT_TOPIC_FAN_MODE: message_arrived_fan_mode(topic, msg); CLIENT.set_callback(custom_dispatcher); # Pretplata na teme CLIENT.subscribe(MQTT_TOPIC_MEASURED_TEMP) CLIENT.subscribe(MQTT_TOPIC_FAN_MODE); # Provjera pristiglih podataka na MQTT def recieve_data(timer): CLIENT.check_msg() CLIENT.check_msg(); recieve_DATA_TIMER = Timer(period=1000, mode=Timer.PERIODIC, callback=recieve_data)

Rad sa temperaturama

Za svaku od tema uvedena je varijabla koja će čuvati odgovarajuću vrijednost na uređaju kako bi se njima

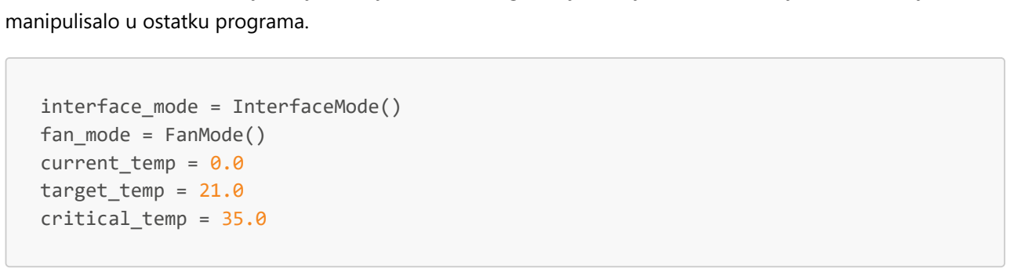
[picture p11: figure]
manipulisalo u ostatku programa.; interface_mode = InterfaceMode() fan_mode = FanMode() current_temp = 0.0 target_temp = 21.0 critical_temp = 35.0

Navedene početne vrijednosti za target_temp i critical_temp su odabrane iz razloga što predstavljaju uobičajen opseg temperatura za stambene prostore, mada nema razloga zašto ne mogu biti u bilo kojem drugom opsegu.

Uvedeno je ograničenje oko minimalne razlike kritične i željene temperature. Najmanja razlika je 5.0°C. Ovo je vrijednost za koju možemo pouzdano tvrditi da neće doći do alarma isključivo zbog greške u mjerenju obzirom da korišteni senzor (LM35) (https://www.ti.com/lit/ds/symlink/lm35.pdf) ima grešku reda 0.5°C pri 25°C. Ova minimalna razlika se može posebno

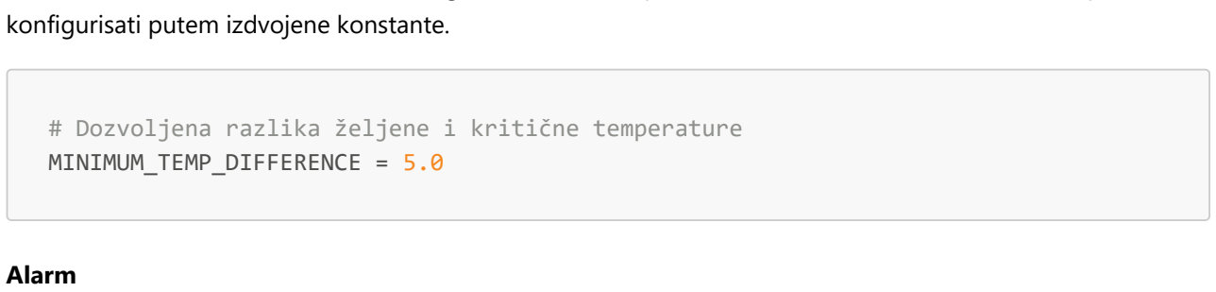
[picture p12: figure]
konfigurisati putem izdvojene konstante.; MINIMUM_TEMP_DIFFERENCE = 5.0; Alarm

# Dozvoljena razlika željene i kritične temperature

Kada mjerena temperatura dosegne kritičnu temperaturu, dolazi do stanja alarma. Kontrolni uređaj na ekranu ispisuje posebnu treptajuću poruku s ciljem da privuće pažnju i upozori na situaciju. Za to vrijeme, neće se ispisivati standardni pogledi. Poruka o alarmu se može skloniti tasterima za promjenu pogleda. Za potrebe implementacije alarm pogleda, koristi se varibajla alarm_now. Varijabla alarm služi kao flag da se dogodilo prekoračenje temperature što trenutno nema drugih koristi ali otvara mogućnost za neku vrstu dijagnostike u

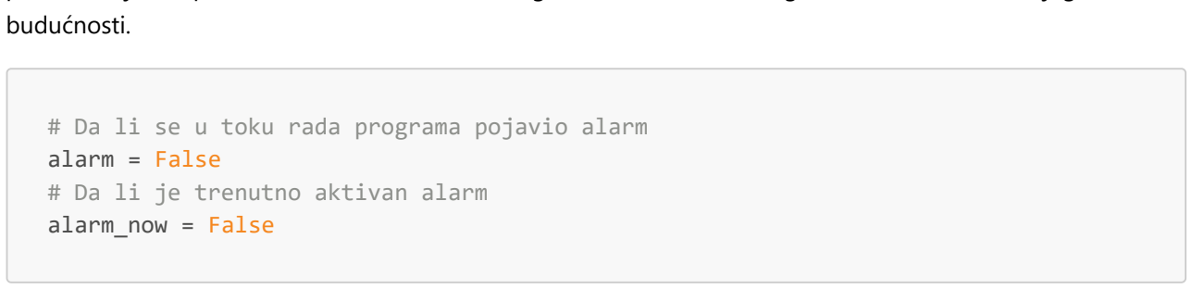
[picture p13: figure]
budućnosti.; alarm = False # Da li je trenutno aktivan alarm alarm_now = False

# Da li se u toku rada programa pojavio alarm

# Terenski uređaj

## main.py

Zadatak je mjeriti i dostavljati temperaturu okruženja, upravljati brzinom ventilatora i signalizirati trenutno stanje. Konfiguracija ovog uređaja se dobavlja sa MQTT brokera.
Mjerenje temperature

Temperatura se mjeri LM35 (https://www.ti.com/lit/ds/symlink/lm35.pdf) senzorom koji ima grešku reda 0.5°C pri 25°C. Ovaj senzor je odabran zbog jednostavnosti implementacije i korištenja. U opticaju je bio i DHT11 (https://www.mouser.com/datasheet/2/758/dht11-technical-data-sheet-translated-version-1143054.pdf) ali ne nudi dovoljnu preciznost i stabilnost u mjerenjima koja je potrebna za ovakav sistem.

Za konkretan LM35 potrebno je odrediti kalibracijsko offset kako bi mjerenje bilo reprezentativno.

Kako očekujemo da se temperatura prostora neće značajno mijenjati u kratkom periodu vremena, korišteno je periodično uzorkovanje od 10 uzoraka. Na osnovu prosječne vrijednosti uzoraka se određuje temperatura. Kalibracijski offset, broj uzoraka i ulazni pin sa A/D konverzijom se konfigurišu u kodu konstantama

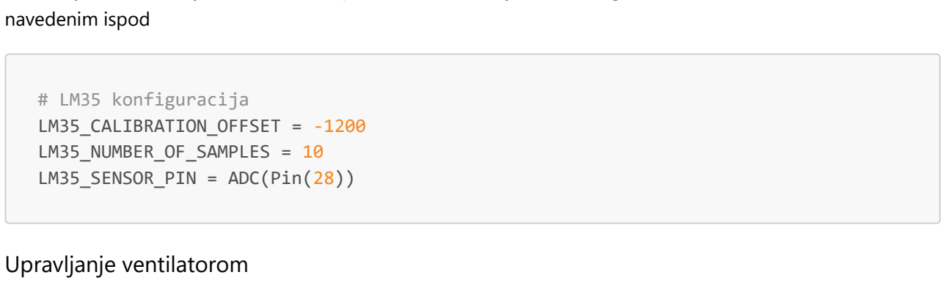
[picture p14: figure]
navedenim ispod; # LM35 konfiguracija LM35_CALIBRATION_OFFSET = -1200 LM35_NUMBER_OF_SAMPLES = 10 LM35_SENSOR_PIN = ADC(Pin(28)); Upravljanje ventilatorom

Ventilator se upravlja PWM signalom sa frekvencijom 500Hz. Obzirom da vrijeme za koje se mijenja brzina ventilatora nije od krucijalnog značaja, frekvencija PWM signala ne mora biti izrazito velika.

Tačan proračun brzine rada ventilatora provodi objekt klase FanSpeedController koja sadrži svu potrebnu

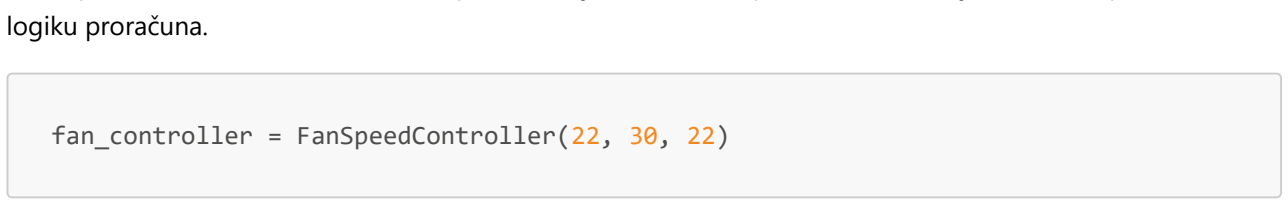
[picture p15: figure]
logiku proračuna.; fan_controller = FanSpeedController(22, 30, 22)

Detaljnije informacije o klasi FanSpeedController ponuđene su u nastavku (Pomoćne klase / FanSpeedController).

Za početne vrijednosti pri instanciranju odabrane su temperature 22°C za željenu, 30°C za kritičnu i 22°C za trenutnu. Ove vrijedonsti se ponovo postavljaju prvim dobavljanjem podataka sa MQTT servisa.

VU Metar

Brzinu i mod ventilatora moguće je vizuleno utvrditi na osnovu šest LED-ova koji svijetle proporcionalno brzini

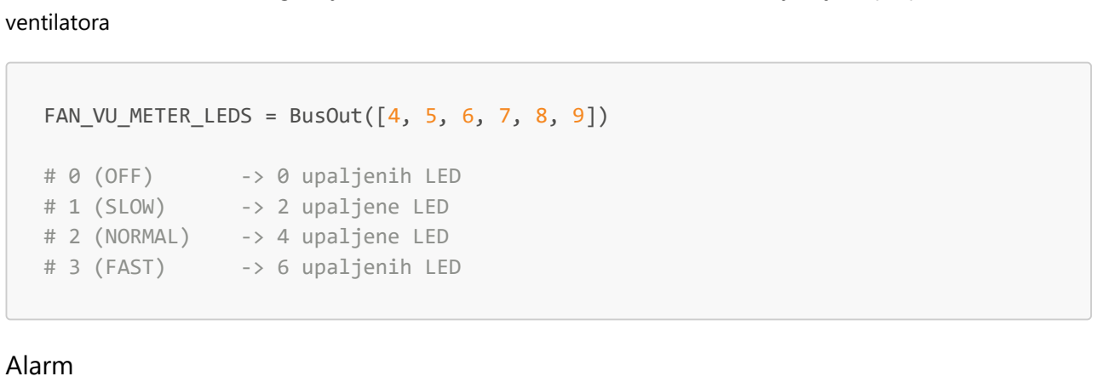
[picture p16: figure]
ventilatora; # 0 (OFF); -> 0 upaljenih LED; # 1 (SLOW); -> 2 upaljene LED; # 2 (NORMAL); -> 4 upaljene LED; # 3 (FAST); -> 6 upaljenih LED; Alarm

FAN_VU_METER_LEDS = BusOut([4, 5, 6, 7, 8, 9])

U slučaju da FanSpeedControler odredi da je trenutna temperatura previsoka, diže se alarm. U slučaju alarma, treperi LED i pali se zujalica kako bi se vizuelno i zvukom privukla pažnja korisnika.

Zujanje alarma se može ugasiti tasterom na uređaju, što omogućuje neometano servisiranje koje je eventualno potrebno.

OVERHEATING_LED = Pin(11, Pin.OUT)

ALARM_PWM = PWM(Pin(27))
ALARM_PWM.freq(1000)

ALARM_OFF_BUTTON = Pin(0, Pin.IN)

# Klikom na taster se gasi alarm ALARM_OFF_BUTTON.irq(handler=turn_alarm_off, trigger=Pin.IRQ_RISING)

MQTT Konektivnost

WiFi konektivnost

Identično kao i na kontrolnom uređaju, prvo se uspostavlja WiFi konekcija.

# WiFi konfiguracija

WIFI_SSID = "naziv_mreze"
WIFI_PASSWORD = "password1234"

# Povezivanje na internet

print("Connecting to WiFi: ", WIFI_SSID) WIFI = network.WLAN(network.STA_IF) WIFI.active(True)
WIFI.config(pm=0xA11140)
WIFI.connect(WIFI_SSID, WIFI_PASSWORD)

while not WIFI.isconnected():
pass

print("Connected to network!") print("IP address:", WIFI.ifconfig()[0])

MQTT Broker i teme

Broker i teme koje se koriste za komunikaciju su identične kao i na kontrolnom uređaju. Jedina razlika je u nazivu klijenta

# MQTT konfiguracija

MQTT_SERVER = "broker.hivemq.com"
MQTT_CLIENT_NAME = "Propuh-Pro-Teren"

MQTT_TOPIC_TARGET_TEMP = b"Propuh-Pro/target_temp" MQTT_TOPIC_CRITICAL_TEMP = b"Propuh-Pro/critical_temp" MQTT_TOPIC_FAN_MODE = b"Propuh-Pro/fan_mode" MQTT_TOPIC_MEASURED_TEMP = b"Propuh-Pro/measured_temp"

Slanje podataka

Terenski uređaj periodično (svakih 0.5 sekundi) šalje isključivo izmjerenu temperaturu nakon svakog

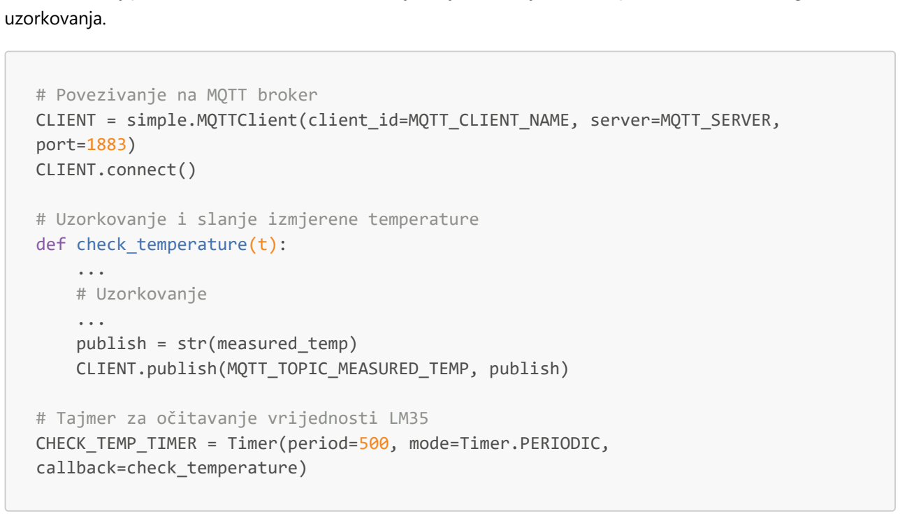
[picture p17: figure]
uzorkovanja.; # Povezivanje na MQTT broker CLIENT = simple.MQTTClient(client_id=MQTT_CLIENT_NAME, server=MQTT_SERVER, port=1883) CLIENT.connect(); def check_temperature(t): ... # Uzorkovanje ... publish = str(measured_temp) CLIENT.publish(MQTT_TOPIC_MEASURED_TEMP, publish); # Tajmer za očitavanje vrijednosti LM35 CHECK_TEMP_TIMER = Timer(period=500, mode=Timer.PERIODIC, callback=check_temperature)

# Uzorkovanje i slanje izmjerene temperature

Dohvaćanje podataka

Podaci sa MQTT brokera se dobavljaju periodično. Funkcija recieve_data se poziva nakon svake sekunde i dobavlja vrijednost željene i kritične temperature i mod ventilatora koji je potencijalno postavljen na moblinom uređaju.

Kada se ustanovi da je postavljena nova vrijednost na brokeru check_msg metodom MQTT klijenta, poziva se custom_dispatcher koji tumači dostavljenu poruku na osnovu teme.

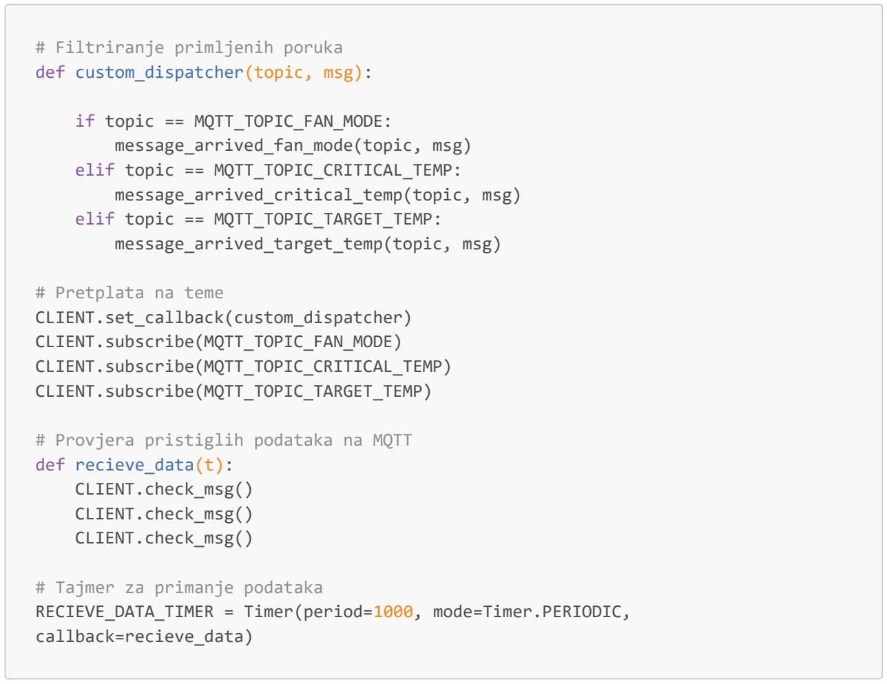
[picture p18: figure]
# Filtriranje primljenih poruka def custom_dispatcher(topic, msg):; if topic == MQTT_TOPIC_FAN_MODE: message_arrived_fan_mode(topic, msg) elif topic == MQTT_TOPIC_CRITICAL_TEMP: message_arrived_critical_temp(topic, msg) elif topic == MQTT_TOPIC_TARGET_TEMP: message_arrived_target_temp(topic, msg); # Pretplata na teme CLIENT.set_callback(custom_dispatcher) CLIENT.subscribe(MQTT_TOPIC_FAN_MODE) CLIENT.subscribe(MQTT_TOPIC_CRITICAL_TEMP) CLIENT.subscribe(MQTT_TOPIC_TARGET_TEMP); # Provjera pristiglih podataka na MQTT def recieve_data(t): CLIENT.check_msg() CLIENT.check_msg() CLIENT.check_msg()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

# Pomoćne klase

## InterfaceMode

InterfaceMode je pomoćna klasa koja enkapsulira broj i naziv modova ili pogleda na ekran. Ova klasa prati State pattern i omogućava promjenu u naredno ili prethodno stanje. Validna stanja su predstavljena kao cijeli brojevi pa se mogu međusobno porediti. Potreba za ovom klasom nastala je jer MicroPython ne poznaje enum klase.

Konstruktor ove klase može da primi jedan parametar - početni pogled, ali je podrazumijevana vrijednost TARGET_TEMP_CONFIG. Primjer instanciranja objekta je dat ispod.

Stanja koja ova klasa poznaje su:

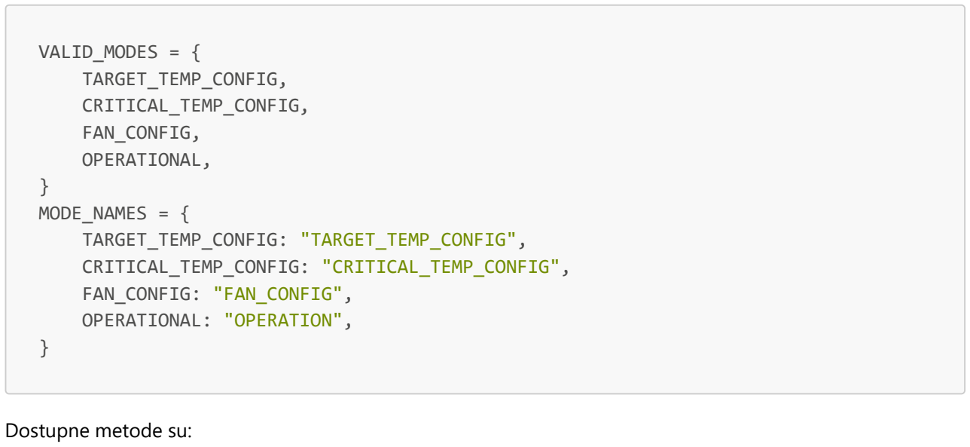
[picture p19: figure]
VALID_MODES = { TARGET_TEMP_CONFIG, CRITICAL_TEMP_CONFIG, FAN_CONFIG, OPERATIONAL,; } MODE_NAMES = { TARGET_TEMP_CONFIG: "TARGET_TEMP_CONFIG", CRITICAL_TEMP_CONFIG: "CRITICAL_TEMP_CONFIG", FAN_CONFIG: "FAN_CONFIG", OPERATIONAL: "OPERATION",; Dostupne metode su:
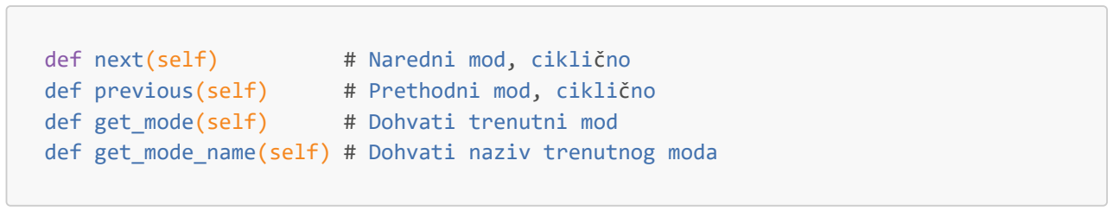
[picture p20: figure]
def next(self); # Naredni mod, ciklično; def previous(self); # Prethodni mod, ciklično; def get_mode(self); # Dohvati trenutni mod

def get_mode_name(self) # Dohvati naziv trenutnog moda

## FanMode

FanMode je također State pattern klasa ali za definisanje modova ventilatora. Tačan intenzitet rada ventilatora nije cilj ove klase. Zapravo, cilj ove klase je da se jasno definišu mogući modovi ventilatora i omogući jasna komunikacija. Kao i za InterfaceMode, stanja se interno čuvaju kao cijeli brojevi.

Konstruktor ove klase može da primi jedan parametar - početni mod, ali je podrazumijevana vrijednost OFF. Primjer instanciranja objekta je dat ispod.

Stanja koja ova klasa poznaje su:

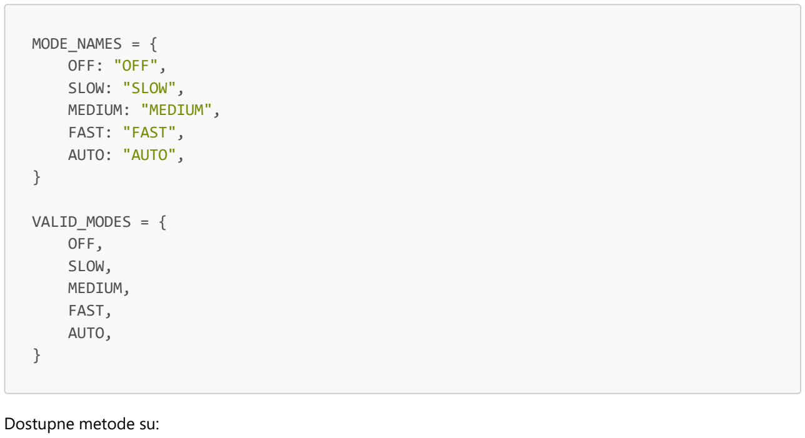
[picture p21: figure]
MODE_NAMES = { OFF: "OFF", SLOW: "SLOW", MEDIUM: "MEDIUM", FAST: "FAST", AUTO: "AUTO",; VALID_MODES = { OFF, SLOW, MEDIUM, FAST, AUTO,; Dostupne metode su:
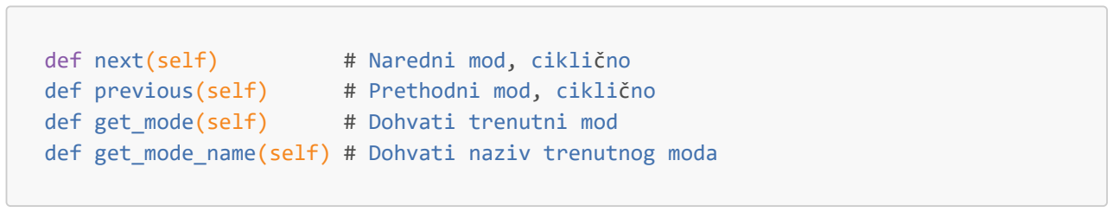
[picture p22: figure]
def next(self); # Naredni mod, ciklično; def previous(self); # Prethodni mod, ciklično; def get_mode(self); # Dohvati trenutni mod

def get_mode_name(self) # Dohvati naziv trenutnog moda

## FanSpeedController

Za enkapsulaciju logike potrebne za određivanje brzine ventilatora na osnovu relevantnih parametara, kreirana je klasa FanSpeedController.

Parametri potrebni za rad ove klase su:

target_temp - double
critical_temp - double
current_temp - double
fan_mode - FanMode objekt

Ove vrijednosti se ujedno proslijeđuju konstruktoru u navedenom redoslijedu. Za fan_mode je podrazumijevana vrijednost FanMode(FanMode.OFF).

Dostupne metode su:

def update_current_speed(self)
# Proračun brzine na osnovu parametara

def set_fan_mode(self, new_fan_mode)
# Postavljanje jednog od modova za ventilator

def get_fan_mode(self)
# Dobavljanje trenutnog moda za ventilator

def set_current_temp(self, new_current_temp) # Postavljanje trenutne temperature

def set_target_temp(self, new_target_temp)
# Postavljanje željene temperature

def set_critical_temp(self, new_critical_temp) # Postavljanje kritične temperature

def is_alarm(self)
# Provjeri je li alarmantna temperatura

def get_speed_percent(self)
# Dohvati brzinu u procentima

def get_speed_u16(self)
# Dohvati temperaturu u opsegu [0, 65535]

def get_led_binary(self)
# Dohvati stanje LED-ova

def turn_alarm_off(self)
# Ugasi alarm

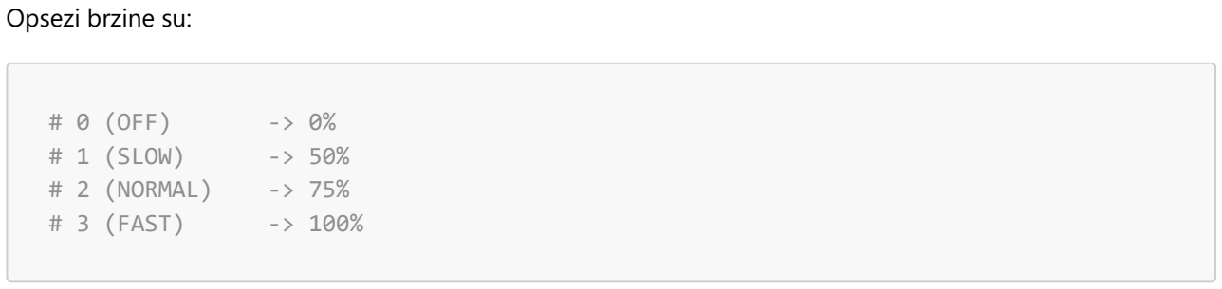
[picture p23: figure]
Opsezi brzine su:; # 0 (OFF); # 1 (SLOW); # 2 (NORMAL); # 3 (FAST)

Za automatski mod, proračun se vrši po opsezima proračunatog procenta kao:

# < -0.1 | -> OFF

# [-0.1, 0.05) -> OFF/SLOW

# [0.05, 0.2) | -> SLOW

# [0.2, 0.3) | -> SLOW/NORMAL

# [0.3, 0.5) | -> NORMAL

# [0.5, 0.6) | -> NORMAL/FAST

# >= 0.6 | -> FAST

## BusOut

Za potrebe rada sa nizom LED-ova, uvedena je klasa BusOut. BusOut omogućujue upravljanjem sa više digitalnih izlaza istovremeno tako što se proslijedi cijeli broj koji predstavlja željeno stanje izlaza. Primjer

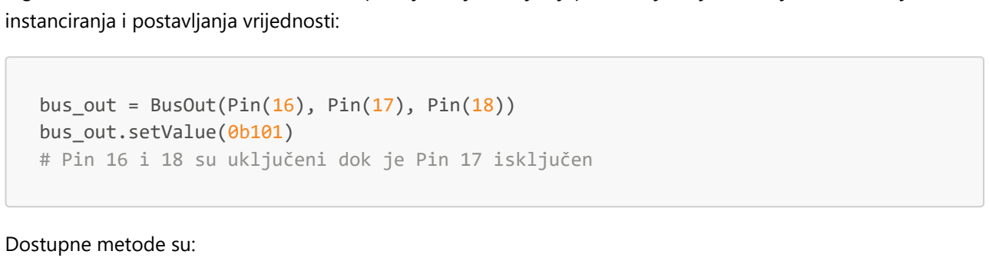
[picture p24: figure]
instanciranja i postavljanja vrijednosti:; bus_out = BusOut(Pin(16), Pin(17), Pin(18)) bus_out.setValue(0b101); Dostupne metode su:

# Pin 16 i 18 su uključeni dok je Pin 17 isključen

def set_value(self, val)
# Postavlja zadatu vrijednost val (integer ili binarni broj)

def size(self)
# Dohvaća broj pinova okjima se upravlja

def get_value(self)
# Dohvaća trenutno postavljenu vrijednost

def shift_right(self, shift_amount=1)
# Pomjera vrijednost izlaza udesno za dati broj bita

def shift_left(self, shift_amount=1)
# Pomjera vrijednost izlaza ulijevo za dati broj bita

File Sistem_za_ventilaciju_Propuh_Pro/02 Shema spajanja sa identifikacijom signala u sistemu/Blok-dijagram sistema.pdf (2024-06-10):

MQTT; Raspberry Pi Pico; Terenski uređaj; Kontrolni uređaj; Android uređaj; MQTT broker (HiveMQ); broker.hivemq.com; IoT MQTT Panel

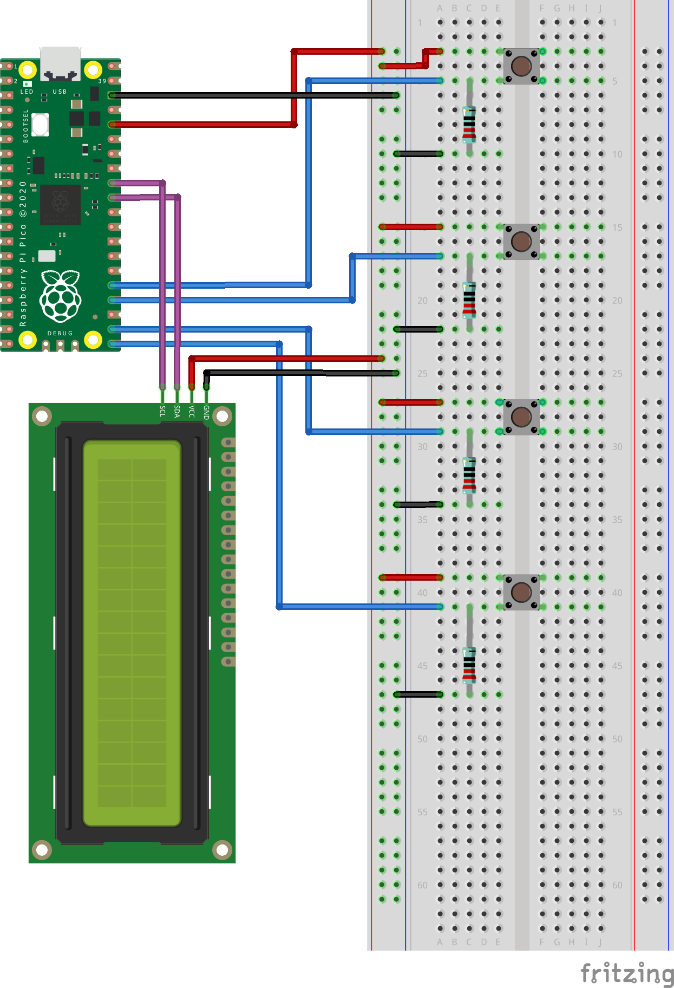
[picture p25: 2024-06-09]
Sistem_za_ventilaciju_Propuh_Pro/02 Shema spajanja sa identifikacijom signala u sistemu/Kontrolni uredjaj/kontrolni_uredjaj_bb.png

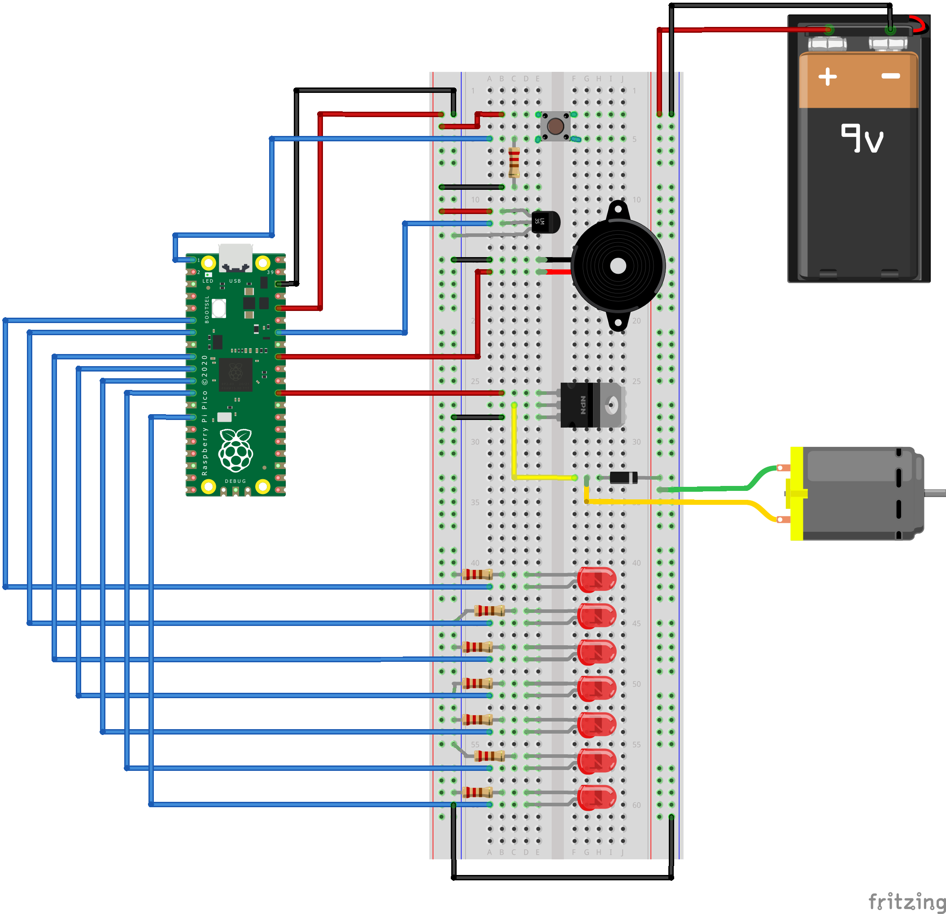
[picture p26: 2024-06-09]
Sistem_za_ventilaciju_Propuh_Pro/02 Shema spajanja sa identifikacijom signala u sistemu/Terenski uredjaj/terenski_uredjaj_bb.png

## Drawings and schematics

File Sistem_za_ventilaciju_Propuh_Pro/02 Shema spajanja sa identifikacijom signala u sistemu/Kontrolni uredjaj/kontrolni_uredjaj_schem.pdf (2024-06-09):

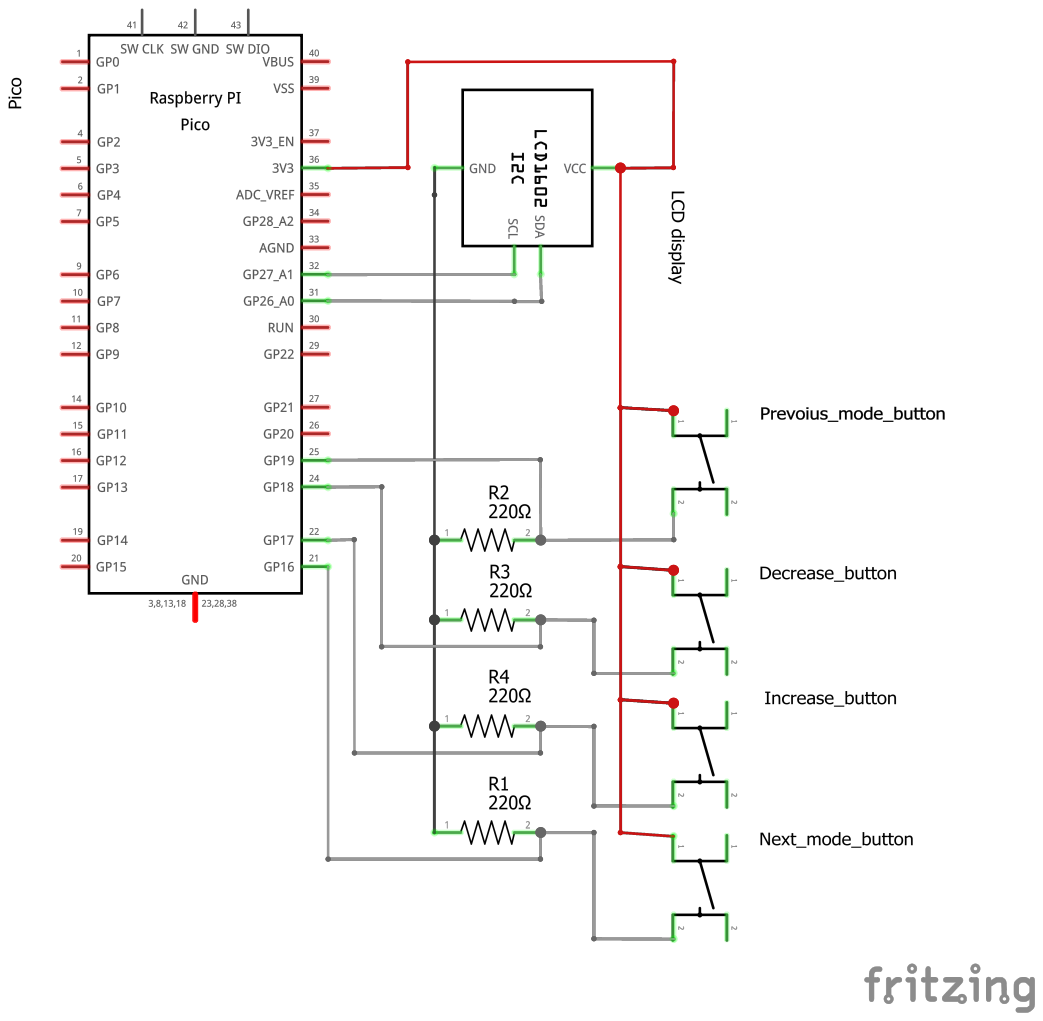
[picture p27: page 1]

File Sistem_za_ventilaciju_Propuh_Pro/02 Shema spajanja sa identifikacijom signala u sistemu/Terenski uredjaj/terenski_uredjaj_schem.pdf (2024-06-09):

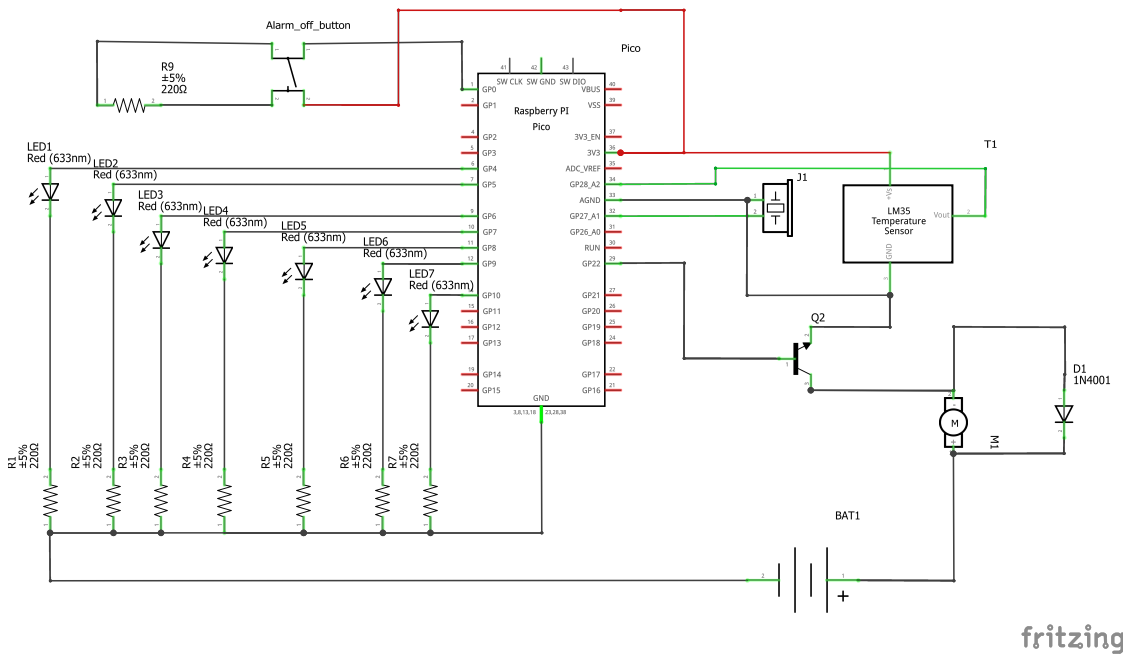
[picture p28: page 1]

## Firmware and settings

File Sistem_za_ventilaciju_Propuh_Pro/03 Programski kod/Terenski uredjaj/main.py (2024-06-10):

from machine import Pin, PWM, ADC, Timer
from time import sleep, ticks_ms, ticks_diff
from FanSpeedController import *
import network
import simple
from BusOut import *


# WiFi konfiguracija 
WIFI_SSID = "iPhone"
WIFI_PASSWORD = "spothot123"

# MQTT konfiguracija
MQTT_SERVER = "broker.hivemq.com"
MQTT_CLIENT_NAME = "Propuh-Pro-Teren"

MQTT_TOPIC_TARGET_TEMP = b"Propuh-Pro/target_temp"
MQTT_TOPIC_CRITICAL_TEMP = b"Propuh-Pro/critical_temp"
MQTT_TOPIC_FAN_MODE = b"Propuh-Pro/fan_mode"
MQTT_TOPIC_MEASURED_TEMP = b"Propuh-Pro/measured_temp"


# Povezivanje na internet
print("Connecting to WiFi: ", WIFI_SSID)
WIFI = network.WLAN(network.STA_IF)
WIFI.active(True)
WIFI.config(pm=0xA11140) 
WIFI.connect(WIFI_SSID, WIFI_PASSWORD)

while not WIFI.isconnected():
    pass

print("Connected to network!")
print("IP address:", WIFI.ifconfig()[0])

#Glavni program - početna konfiguracija

FAN_VU_METER_LEDS = BusOut([4, 5, 6, 7, 8, 9])

OVERHEATING_LED = Pin(11, Pin.OUT)

FAN_PWM = PWM(Pin(22))
FAN_PWM.freq(500)

ALARM_PWM = PWM(Pin(27))
ALARM_PWM.freq(1000)

ALARM_OFF_PIN = Pin(0, Pin.IN)

# LM35 konfiguracija
LM35_CALIBRATION_OFFSET = -1200
LM35_NUMBER_OF_SAMPLES = 10
LM35_SENSOR_PIN = ADC(Pin(28))

temp_sum = 0.0
measured_temp = 0.0
sample_counter = 0
alarm = 0

# FanSpeedController sadrži sve neophodne informacije za rad sistema
fan_controller = FanSpeedController(22, 30, 22)

DEBOUNCE_TIME_MS = 300
debounce = 0


def debouncing():
    global debounce
    if ticks_diff(ticks_ms(), debounce) < DEBOUNCE_TIME_MS:
        return False
    else:
        debounce = ticks_ms()
        return True

# Ažuriranje snage ventilatora i stanja LED
def update_system():
    global alarm, fan_controller

    # Uzimanje trenutnih podataka unutar kontrolera
    speed = int(fan_controller.get_speed_u16())
    light = int(fan_controller.get_led_binary())

    # Ukoliko se alarm treba upaliti, a prethodno nije bio
    if fan_controller.is_alarm() and alarm == 0:
        turn_alarm_on()

    # Ukoliko je alarm upaljen, a treba se ugasiti
    elif (not fan_controller.is_alarm()) and alarm == 1:
        turn_alarm_off(ALARM_OFF_PIN)

    set_fan_speed(speed)
    update_vu_meter(light)

# Očitavanje trenutne temperature
def check_temperature(t):
    global sample_counter, temp_sum, measured_temp, fan_controller

    voltage = ((LM35_SENSOR_PIN.read_u16() + LM35_CALIBRATION_OFFSET) / 65535) * 3.3
    temp_sum += round(voltage * 100, 1)
    sample_counter += 1

    # Uzima se prosjek
    if sample_counter == LM35_NUMBER_OF_SAMPLES:
        measured_temp = temp_sum / LM35_NUMBER_OF_SAMPLES

        sample_counter = 0
        temp_sum = 0
        print("Average temperature=", measured_temp)
        
        #Ažuriranje podataka unutar kontrolera
        fan_controller.set_current_temp(measured_temp)
        
        # Slanje izmjerene temperature
        publish = str(measured_temp)
        CLIENT.publish(MQTT_TOPIC_MEASURED_TEMP, publish)

        update_system()

# Paljenje/gašenje LED i emitovanje zvuka
def toggle_alarm(t):
    global alarm

    if OVERHEATING_LED.value() == 1:
        OVERHEATING_LED.off()
        ALARM_PWM.duty_u16(45000)
    else:
        OVERHEATING_LED.on()
        ALARM_PWM.duty_u16(10000)

# Klikom na taster se gasi alarm
def turn_alarm_off(pin):
    global fan_controller, measured_temp

    fan_controller.turn_alarm_off()
    ALARM_PWM.duty_u16(0)
    OVERHEATING_LED.off()

    # Deinicijalizira se tajmer za alarm 
    ALARM_TIMER.deinit()

# Postavlja se brzina ventilatora putem PWM izlaza
def set_fan_speed(duty_u16):
    FAN_PWM.duty_u16(duty_u16)

# Ažuriranje LED
def update_vu_meter(number):
    FAN_VU_METER_LEDS.set_value(number)

# Paljenje alarma
def turn_alarm_on():
    global ALARM_TIMER, alarm, OVERHEATING_LED, ALARM_PWM

    alarm = 1
    OVERHEATING_LED.on()
    ALARM_PWM.duty_u16(3000)

    # Inicijalizira se tajmer za paljenje/gašenje LED i emitovanje zvuka
    ALARM_TIMER = Timer(period=500, mode=Timer.PERIODIC, callback=toggle_alarm)

# Primljena nova vrijednost stanja ventilatora preko MQTT
def message_arrived_fan_mode(topic, msg):
    global fan_controller

    print("Message arrived on topic:", topic)
    print("Payload:", msg)
    fan_controller.set_fan_mode(FanMode(int(float(msg))))

    update_system()

# Primljena nova vrijednost kritične temperature
def message_arrived_critical_temp(topic, msg):
    global fan_controller

    print("Message arrived on topic:", topic)
    print("Payload:", msg)
    fan_controller.set_critical_temp(float(msg))

    update_system()

# Primljena nova vrijednost željene temperature
def message_arrived_target_temp(topic, msg):
    global fan_controller

    print("Message arrived on topic:", topic)
    print("Payload:", msg)
    fan_controller.set_target_temp(float(msg))

    update_system()

# Filtriranje primljenih poruka
def custom_dispatcher(topic, msg):
    
    if topic == MQTT_TOPIC_FAN_MODE:
        message_arrived_fan_mode(topic, msg)
    elif topic == MQTT_TOPIC_CRITICAL_TEMP:
        message_arrived_critical_temp(topic, msg)
    elif topic == MQTT_TOPIC_TARGET_TEMP:
        message_arrived_target_temp(topic, msg)


# Povezivanje na MQTT broker
CLIENT = simple.MQTTClient(client_id=MQTT_CLIENT_NAME, server=MQTT_SERVER, port=1883)
CLIENT.connect()

# Pretplata na teme
CLIENT.set_callback(custom_dispatcher)
CLIENT.subscribe(MQTT_TOPIC_FAN_MODE)
CLIENT.subscribe(MQTT_TOPIC_CRITICAL_TEMP)
CLIENT.subscribe(MQTT_TOPIC_TARGET_TEMP)

# Primanje podataka sa MQTT
def recieve_data(t):
    CLIENT.check_msg()
    CLIENT.check_msg()
    CLIENT.check_msg()

# no operation
def nop(t):
    pass

# Tajmer za očitavanje vrijednosti LM35
CHECK_TEMP_TIMER = Timer(period=500, mode=Timer.PERIODIC, callback=check_temperature)
# Tajmer za primanje podataka
RECIEVE_DATA_TIMER = Timer(period=1000, mode=Timer.PERIODIC, callback=recieve_data)

# Klikom na taster se gasi alarm
ALARM_OFF_PIN.irq(handler=turn_alarm_off, trigger=Pin.IRQ_RISING)
ALARM_TIMER = Timer(period=100, mode=Timer.ONE_SHOT, callback=nop)

while True:
    pass

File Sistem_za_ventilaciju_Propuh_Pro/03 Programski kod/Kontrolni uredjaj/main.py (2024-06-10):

from machine import Pin, I2C, Timer
from time import ticks_ms, ticks_diff
from FanMode import *
from InterfaceMode import *
from utime import sleep
from lcd_api import LcdApi
from pico_i2c_lcd import I2cLcd
import network
import simple

# Display konfiguracija
I2C_ADDR = 0x27
I2C_NUM_ROWS = 2
I2C_NUM_COLS = 16

I2C_BUS = I2C(1, sda=Pin(26), scl=Pin(27), freq=400000)
LCD_DISPLAY = I2cLcd(I2C_BUS, I2C_ADDR, I2C_NUM_ROWS, I2C_NUM_COLS)

# WiFi konfiguracija
WIFI_SSID = "iPhone"
WIFI_PASSWORD = "spothot123"

# MQTT konfiguracija
MQTT_SERVER = "broker.hivemq.com"
MQTT_CLIENT_NAME = "Propuh-Pro-Control"

MQTT_TOPIC_TARGET_TEMP = b"Propuh-Pro/target_temp"
MQTT_TOPIC_CRITICAL_TEMP = b"Propuh-Pro/critical_temp"
MQTT_TOPIC_FAN_MODE = b"Propuh-Pro/fan_mode"
MQTT_TOPIC_MEASURED_TEMP = b"Propuh-Pro/measured_temp"


# Povezivanje na internet
print("Connecting to WiFi: ", WIFI_SSID)
WIFI = network.WLAN(network.STA_IF)
WIFI.active(True)
WIFI.config(pm=0xA11140)
WIFI.connect(WIFI_SSID, WIFI_PASSWORD)

LCD_DISPLAY.putstr("Connecting...")

while not WIFI.isconnected():
    pass

print("Connected to network!")
print("IP address:", WIFI.ifconfig()[0])

# Glavni program - početna konfiguracija
NEXT_MODE_BUTTON = Pin(16, Pin.IN)
PREVIOUS_MODE_BUTTON = Pin(19, Pin.IN)
INCREASE_BUTTON = Pin(17, Pin.IN)
DECRESE_BUTTON = Pin(18, Pin.IN)

# Dozvoljena razlika željene i kritične temperature
MINIMUM_TEMP_DIFFERENCE = 5.0

DEBOUNCE_TIME_MS = 300

fan_mode = FanMode()
interface_mode = InterfaceMode()
current_temp = 22.0
target_temp = 20.0
critical_temp = 27.0

debounce = 0
# Da li se u toku rada programa pojavio alarm
alarm = False
# Da li je trenutno aktivan alarm
alarm_now = False


def debouncing():
    global debounce
    if ticks_diff(ticks_ms(), debounce) < DEBOUNCE_TIME_MS:
        return False
    else:
        debounce = ticks_ms()
        return True


def next_mode(pin):
    global alarm_now, interface_mode

    if debouncing() == False:
        return

    # Prekid alarma ukoliko je isti aktiviran
    alarm_now = False
    interface_mode.next()
    print_configuration()


def previous_mode(pin):
    global alarm_now, interface_mode

    if debouncing() == False:
        return

    # Prekid alarma ukoliko je isti aktiviran
    alarm_now = False
    interface_mode.previous()
    print_configuration()


def increase_value(pin):
    global target_temp
    global critical_temp
    global alarm_now
    global SEND_DATA_TIMER
    if debouncing() == False:
        return


    if interface_mode.get_mode() == InterfaceMode.OPERATIONAL:
        return
    
    # Prekid alarma ukoliko je isti aktiviran
    alarm_now = False

    # Da li su temperature u dozvoljenom opsegu
    if interface_mode.get_mode() == InterfaceMode.TARGET_TEMP_CONFIG:
        if critical_temp - target_temp > MINIMUM_TEMP_DIFFERENCE:
            target_temp += 0.5
    elif interface_mode.get_mode() == InterfaceMode.CRITICAL_TEMP_CONFIG:
        critical_temp += 0.5
    elif interface_mode.get_mode() == InterfaceMode.FAN_CONFIG:
        fan_mode.next()

    SEND_DATA_TIMER = Timer(period=3000, mode=Timer.ONE_SHOT, callback=send_data)
    print_configuration()


def decrease_value(pin):
    global target_temp
    global critical_temp
    global alarm_now
    global SEND_DATA_TIMER

    if debouncing() == False:
        return

    if interface_mode.get_mode() == InterfaceMode.OPERATIONAL:
        return

    # Prekid alarma ukoliko je isti aktiviran
    alarm_now = False

    # Da li su temperature u dozvoljenom opsegu
    if interface_mode.get_mode() == InterfaceMode.TARGET_TEMP_CONFIG:
        target_temp -= 0.5
    elif interface_mode.get_mode() == InterfaceMode.CRITICAL_TEMP_CONFIG:
        if critical_temp - target_temp > MINIMUM_TEMP_DIFFERENCE:
            critical_temp -= 0.5
    elif interface_mode.get_mode() == InterfaceMode.FAN_CONFIG:
        fan_mode.previous()

    SEND_DATA_TIMER = Timer(period=3000, mode=Timer.ONE_SHOT, callback=send_data)
    print_configuration()


# Aktivacija alarma i prikaz upozorenja
def print_alarm():
    global alarm, alarm_now

    alarm = True
    alarm_now = True
    alarm_blink_counter = 0

    while alarm_blink_counter <= 5 and alarm_now:
        LCD_DISPLAY.clear()
        sleep(0.5)
        LCD_DISPLAY.putstr(
            "TEMPERATURE     CRITICAL: " + str(current_temp) + chr(223) + "C"
        )
        sleep(0.8)

        alarm_blink_counter += 1


# Ispis informacija na display
def print_configuration():

    # Ukoliko je alarm aktivan neće se ažurirati display
    if alarm_now:
        return

    fan_output = ""

    if fan_mode == FanMode.AUTO:
        fan_output = "AUTO"
    else:
        mode_outputs = {
            FanMode.OFF: "O O O",
            FanMode.SLOW: "# O O",
            FanMode.MEDIUM: "# # O",
            FanMode.FAST: "# # #",
            FanMode.AUTO: "AUTO",
        }
        fan_output = mode_outputs.get(fan_mode.current_mode, "UNKNOWN")

    print()
    print("Mode:", interface_mode.get_mode_name())

    current_mode = interface_mode.get_mode()

    if current_mode == InterfaceMode.TARGET_TEMP_CONFIG:
        output = "Target temp:    " + str(target_temp) + chr(223) + "C"
        print(output)
        LCD_DISPLAY.clear()
        LCD_DISPLAY.putstr(output)

    elif current_mode == InterfaceMode.CRITICAL_TEMP_CONFIG:
        output = "Critical temp:  " + str(critical_temp) + chr(223) + "C"
        print(output)
        LCD_DISPLAY.clear()
        LCD_DISPLAY.putstr(output)

    elif current_mode == InterfaceMode.FAN_CONFIG:
        output = "Fan speed:      " + str(fan_output)

        if fan_mode.get_mode() != FanMode.AUTO:
            output = output + "   " + fan_mode.get_mode_name()

        print(output)
        LCD_DISPLAY.clear()
        LCD_DISPLAY.putstr(output)

    else:
        output = "Current temp:   " + str(current_temp) + chr(223) + "C"
        print(output)
        LCD_DISPLAY.clear()
        LCD_DISPLAY.putstr(output)


# Korak za temperaturu je 0.5
def round_to_nearest_half(value) -> float:
    return round(value * 2) / 2


# Primljena nova vrijednost izmjerene temperature
def message_arrived_measured_temp(topic, msg):
    global current_temp

    print("Message arrived on topic:", topic)
    print("Payload:", msg)

    if current_temp == round_to_nearest_half(float(msg)):
        return

    current_temp = round_to_nearest_half(float(msg))

    if current_temp >= critical_temp and alarm == False:
        print_alarm()
        return

    if interface_mode.get_mode() == InterfaceMode.OPERATIONAL:
        print_configuration()


# Primljena nova vrijednost za fan mode
def message_arrived_fan_mode(topic, msg):
    global fan_mode, current_mode

    print("Message arrived on topic:", topic)
    print("Payload:", msg)

    if fan_mode.current_mode == int(msg):
        return

    fan_mode.current_mode = int(msg)

    if interface_mode.get_mode() == InterfaceMode.FAN_CONFIG:
        print_configuration()
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

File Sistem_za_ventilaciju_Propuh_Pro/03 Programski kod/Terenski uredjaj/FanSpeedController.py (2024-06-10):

# Moguća stanja ventilatora
class FanMode:
    OFF = 0
    SLOW = 1
    MEDIUM = 2
    FAST = 3
    AUTO = 4

    MODE_NAMES = {
        OFF: "OFF",
        SLOW: "SLOW",
        MEDIUM: "MEDIUM",
        FAST: "FAST",
        AUTO: "AUTO",
    }

    VALID_MODES = {
        OFF,
        SLOW,
        MEDIUM,
        FAST,
        AUTO,
    }

    def __init__(self, starting_mode=OFF):

        if starting_mode not in self.VALID_MODES:
            raise ValueError(
                f"Invalid starting mode: {starting_mode}. Must be one of {FanMode.MODE_NAMES}."
            )

        self.current_mode : int = starting_mode
        self.length = len(self.VALID_MODES)

    def next(self):
        self.current_mode = (self.current_mode + 1) % self.length

    def previous(self):
        self.current_mode = (self.current_mode - 1) % self.length

    def get_mode(self) -> int:
        return self.current_mode

    def get_mode_name(self):
        return FanMode.MODE_NAMES.get(self.current_mode, "UNKNOWN")

# Upravljanje snagom ventilatora
class FanSpeedController:

    def __init__(self, target_temp, critical_temp, current_temp, fan_mode = FanMode(FanMode.OFF)):
        self.target_temp = target_temp
        self.critical_temp = critical_temp
        self.fan_mode = fan_mode

        # Brzina odgovara stanjima ventilatora
        self.current_speed = 0

        self.current_temp = current_temp
        self.alarm = False

        # Intervali rada za svako stanje ventilatora
        # < -0.1 -> OFF
        # [-0.1, 0.05) -> OFF/SLOW
        # [0.05, 0.2) -> SLOW
        # [0.2, 0.3) -> SLOW/NORMAL
        # [0.3, 0.5) -> NORMAL
        # [0.5, 0.6) -> NORMAL/FAST
        # >= 0.6 -> FAST
        self.working_regions = [(-0.1, 0.05), (0.05, 0.2), (0.2, 0.3), (0.3, 0.5), (0.5, 0.6)] 

    # Metoda za ažuriranje trenutne brzine, poziva se nakon svake promjene podataka
    def update_current_speed(self):
        # Trenutna temperatura u odnosu na željenu i kritičnu
        range = self.critical_temp - self.target_temp
        percentage = (self.current_temp - self.target_temp) / range 

        # Ukoliko nije AUTO stanje brzina je jednaka tom stanju
        if self.fan_mode.get_mode() != FanMode.AUTO:
            self.current_speed = self.fan_mode.get_mode()

            # Ukoliko je željena temperatura veća od kritične pali se alarm
            if percentage >= 1:
                self.alarm = True
            return
        
        if percentage < self.working_regions[0][0]:
            self.current_speed = 0 #OFF
        elif percentage >= self.working_regions[len(self.working_regions) - 1][1]:
            self.current_speed = 3 #FAST
            if percentage >= 1:
                self.alarm = True
                return
        else:
            i = 0
            j = 1
            new_speed = 0
            for low_border, top_border in self.working_regions:
                if low_border <= percentage < top_border:
                    # Kada je i = 0 trenutna temp. se nalazi u jednom od intervala gdje su moguće dvije brzine ventilatora
                    # Ventilator u tom slučaju ostaje u brzinu u kojoj je trenutno
                    # Ukoliko nije ni u jednoj od te dvije brzine, ventilator prelazi u brzinu koja je bliža trenutnoj
                    if i == 0:
                        if self.current_speed != new_speed and self.current_speed != new_speed + 1:
                            if self.current_speed < new_speed:
                                self.current_speed = new_speed
                            else:
                                self.current_speed = new_speed + 1
                    # Za i = 1 poznata je sljedeća brzina ventilatora 
                    else:
                        self.current_speed = new_speed
                    break
                j += 1
                if j == 2:
                    new_speed += 1
                    j = 0
                i = (i + 1) % 2
        self.turn_alarm_off()

    # Setteri i getteri za atribute 
    def set_fan_mode(self, new_fan_mode):
        self.fan_mode = new_fan_mode

        # U svakoj set metodi se ažurira brzina
        self.update_current_speed()

    def get_fan_mode(self):
        return self.fan_mode
    
    def set_current_temp(self, new_current_temp):
        self.current_temp = new_current_temp
        self.update_current_speed()

    def set_target_temp(self, new_target_temp):
        self.target_temp = new_target_temp
        if self.target_temp <= self.critical_temp - 5:
            self.update_current_speed()

    def set_critical_temp(self, new_critical_temp):
        self.critical_temp = new_critical_temp
        self.update_current_speed()
    
    def is_alarm(self):
        return self.alarm
    
    # Brzina u postotcima
    def get_speed_percent(self):
        # 0 (OFF) -> 0%
        # 1 (SLOW) -> 50%
        # 2 (NORMAL) -> 75%
        # 3 (FAST) -> 100%
        if self.current_speed == 0:
            return 0.0
        return (self.current_speed + 1) / (len(FanMode.VALID_MODES) - 1) # Ovo mozda prepraviti

    # Za postavljanje duty cycle-a PWM izlaza
    def get_speed_u16(self):
        U16 = 2**16 - 1
        return U16 * self.get_speed_percent()
    
    # Za prikaz brzine putem LED
    def get_led_binary(self):
        # 0 (OFF) -> 0 upaljenih LED
        # 1 (SLOW) -> 2 upaljene LED
        # 2 (NORMAL) -> 4 upaljene LED
        # 3 (FAST) -> 6 upaljenih LED
        return bin(2**(2 * self.current_speed) - 1)
    
    #Gašenje alarma
    def turn_alarm_off(self):
        self.alarm = False

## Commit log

2024-05-29 Folder za terenski uredjaj i privremeno Pico W i picoET pinout diagram
2024-05-29 Printanje trenutne konfiguracije sistema kao za Display
2024-05-29 Konfiguracija kriticne temperature implementirana
2024-05-30 lcd1602 prepravljeno na 3.3V, default je 5V
2024-05-30 LCD mora na 5V, ima error za neki PIN
    [main.py]
2024-05-30 Display output radi - print_configuration() funkcija
2024-06-01 temperature sensor
2024-06-01 FanMode izdvojen, Timer za recive_data i minimalna razlika target i critical temp
2024-06-02 Disable powersave mode - navodno stabilnija veza na WiFi
2024-06-02 current_temp se ispisuje zaokruzeno na najblizu polovinu stepena
2024-06-02 Print formatiranje
2024-06-02 implemented fan speed synchronization
2024-06-03 fixed updating of fan speed and added alarm functionality
    [FanSpeedController.py, main.py]
2024-06-03 Ispis naziva fan moda
2024-06-03 Ispis alarma u slucaju da je current temp >= critical temp
2024-06-03 Ispisuje se i temperatura kada je ktiricna
2024-06-04 sending current temp with mqtt
2024-06-09 Fritzing files
    [Kontrolni uređaj.fzz, Terenski_uređaj.fzz]
2024-06-10 Kontrolni uredjaj prima samo mjerenu temperaturu i fan mod, kao na branch-u ideja
2024-06-10 U Operational modu se ne poziva print_config na increase i decrease taster
2024-06-10 Predaja projekta
    [kontrolni_uredjaj.fzz, terenski_uredjaj.fzz]
